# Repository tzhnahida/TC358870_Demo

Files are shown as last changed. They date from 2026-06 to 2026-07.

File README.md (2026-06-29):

# TC358870XBG HDMI-to-MIPI DSI Bridge — Evaluation Board

> **PCB Rev 1.0 is deprecated.** Do not fabricate. MIPI DSI lane swap errata + HPD wiring errors.
> **Rev 2.0:** Layout complete. HDMI SI/PI simulation passed. Gerber released — ready for fabrication.

A 4-layer PCB for the Toshiba TC358870XBG, converting HDMI 1.4b (up to 297 MHz TMDS) to dual 4-lane MIPI DSI (up to 1 Gbps/lane). Designed to drive a Sharp LS029B3SX01 1440×1440@90Hz LCD panel.

---

## Hardware

### Key Components

| Designator | Part | Function |
|---|---|---|
| U1 | TYPE-C 16-pin | 5V power input (USB-C) |
| U2 | TLV62569DBV | 5V→3.3V DCDC buck (VCC_3V3) |
| U3 | LP5907MFX | 3.3V→1.2V LDO (VCC_1V2) |
| U4 | TLV62569DBV | 5V→1.1V DCDC buck (VCC_1V1) |
| U5 | LP5907MFX | 3.3V→1.8V LDO (VCC_1V8) |
| U6 | TPS65131RGER | 5V→±5.5V charge pump (panel AVDD/AVEE) |
| U7 | SGM3752YTN6G | 3.3V→LED backlight boost (22mA max) |
| U8 | AT24C02 (SOP-8) | DDC EEPROM, EDID storage |
| U9A/B/C/D | TC358870XBG (BGA80) | HDMI Rx → dual MIPI DSI Tx (4-page schematic) |
| ESD1/2/3 | IP4292CZ10 | HDMI ESD protection |
| Q1 | PMOS | Power switch |
| OSC1 | 40 MHz | REFCLK for TC358870 |
| J1 | HDMI-A | HDMI input connector |
| J2 | WP7 (JAE 40-pin) | Panel FPC, mates with LS029B3SX01 |

### Power Rails

| Rail | Voltage | Source | Load |
|---|---|---|---|
| VCC_5V | 5.0V | USB-C | Input bus |
| VCC_3V3 | 3.3V | 5V→3.3V DCDC buck (TLV62569) | TC358870 VDDIO33, VDD33_HDMI; feeds LDOs + LED |
| VCC_1V8 | 1.8V | 3.3V→1.8V LDO (LP5907) | TC358870 VDDIO18 |
| VCC_1V2 | 1.2V | 3.3V→1.2V LDO (LP5907) | TC358870 VDD12_MIPI0/1 |
| VCC_1V1 | 1.1V | 5V→1.1V DCDC buck (TLV62569) | TC358870 VDDC11, VDD11_HDMI |
| VCC_5V5 | +5.5V | 5V charge pump (TPS65131) | LS029 AVDD+ |
| VEE_5V5 | -5.5V | 5V charge pump (TPS65131) | LS029 AVEE- |
| VCC_HDMIRX_IN | +5V (from HDMI source) | HDMI pin 18 | DDC pull-up |

### PCB Stack-Up (4-layer)

| Layer | Type |
|---|---|
| TOP | Signal (HDMI, MIPI, I2C, REFCLK) |
| L2 | Solid GND plane |
| L3 | Split POWER plane |
| BOTTOM | Signal, decoupling, test points |

---

## Known Issues

### AT24C256 → AT24C02 ✅ Resolved in Schematic

Schematic symbol value updated to AT24C02 (2026-06-29). Original AT24C256 uses **2-byte I2C addressing** — incompatible with HDMI DDC which only sends 1 address byte for EDID reads. AT24C02 uses same SOP-8 footprint and 1-byte addressing (¥0.5). PCB footprint unchanged. Library symbol name still shows "AT24C256" but BOM and silk-screen will read AT24C02.

### EDID: External EEPROM Only

TC358870 contains 1 KB internal EDID SRAM, but **its I2C sub-address is not documented in the public datasheet** (`TC358870XBG_rev1.3.pdf`). Use external AT24C02 on the DDC bus with `EDID_MODE = 0x00` (DDC passthrough to EEPROM).

### Rev 1.0 Errata

| Signal | Issue | Fix |
|---|---|-----|
| MIPI DSI lanes | Lane/clock pair order swapped per datasheet | Re-route per pin mapping |
| HPDO (B4) | Shorted to +5V | Cut trace, add 1kΩ to HDMI pin 19 |
| HPDI (A4) | Connected to HPD pin | Move to HDMI pin 18 (+5V) via 100kΩ |

---

## EDID

The board ships with a 256-byte EDID for LS029B3SX01 (1440×1440@90.2Hz). Flash this to the AT24C02 via the DDC bus (STM32 can take control while TC358870 is held in reset):

```c
const uint8_t edid_ls029b3sx01[256] = {
    0x00,0xFF,0xFF,0xFF,0xFF,0xFF,0xFF,0x00,
    0x4D,0x10,0x02,0x29,0x01,0x00,0x00,0x00,
    0x1A,0x24,0x01,0x03,0x80,0x34,0x34,0x78,
    0xEE,0x91,0x50,0x54,0x9C,0x27,0x0E,0x50,
    0x54,0xBF,0xEF,0x00,0x00,0x00,0x01,0x01,
    0x01,0x01,0x01,0x01,0x01,0x01,0x01,0x01,
    0x01,0x01,0x01,0x01,0x01,0x01,0x2F,0x66,
    0xA0,0xFE,0x50,0xA0,0x10,0x51,0x9A,0x04,
    0xF1,0xC0,0x34,0x34,0x10,0x00,0x00,0x00,
    0x00,0x00,0x00,0x00,0x00,0x00,0x00,0x00,
    0x00,0x00,0x00,0x00,0x00,0x00,0x00,0x00,
    0x00,0x00,0x00,0x00,0x00,0xFD,0x00,0x32,
    0x5E,0x14,0xA0,0x1E,0x00,0x00,0x00,0x00,
    0x00,0x0A,0x00,0x00,0x00,0x00,0x00,0xFC,
    0x00,0x4C,0x53,0x30,0x32,0x39,0x42,0x33,
    0x53,0x58,0x30,0x31,0x00,0x00,0x01,0x19,
    0x02,0x03,0x0E,0x00,0x21,0x01,0x67,0x00,
    0x0C,0x03,0x01,0x00,0x00,0x00,0x00,0x00,
    // ... (see wiki LS029B3SX01.md for full verified array)
};
// Checksums: Block0=0x19, Block1=0x54
// 1440×1440, 261.6 MHz pixel clock, 90.2 Hz
```

---

## Firmware

### Register Initialization Sequence

The STM32 (or any I2C master at 0x0F/0x1F) must write this sequence at power-up:

```
 1. SYSCTL     (0x0002) = 0x3F01   // full reset + SLEEP, delay 1ms
 2. SYSCTL     (0x0002) = 0x0000   // release
 3. ConfCtl0   (0x0004) = 0x0004   // AutoIndex=1
 4. ConfCtl1   (0x0006) = 0x0008   // dcs_clks=1
 5. SYS_FREQ0  (0x8540) = ...      // REFCLK_Hz / 10000  LSB
 6. SYS_FREQ1  (0x8541) = ...      // REFCLK_Hz / 10000  MSB
 7. EDID_MODE  (0x85E0) = 0x00     // DDC passthrough to external EEPROM
 8. DDCIO_CTL  (0x84F4): 0→1      // DDC I/O power-up edge
 9. DDC_CTL    (0x8543) = 0x04     // DDC_ACTION=1
10. PHY_ENB    (0x8413) |= 0x01    // exit Suspend
11. PHY_RSTX   (0x8414) |= 0x01    // release PHY reset
12. VOUT_FMT   (0x8A00) = 0x00     // RGB output
13. VOUT_CSC   (0x8A08) = 0x00     // no CSC
14. ConfCtl0   (0x0004) = 0x0007   // Vtx0_en + Vtx1_en + AutoIndex
15. INIT_END   (0x854A) = 0x01     // init complete
16. HPD_CTL    (0x8544) = 0x01     // assert HPD
```

### DSI Configuration (40 MHz REFCLK, 800 Mbps/lane target)

```
MIPI_PLL_CONF (0x02AC) = 0x0003793F  // {0x3F,0x79,0x03,0x00}
//   FBD=319, PRD=7, FRS=2, LBW=max
//   pll_clk = 40MHz × 320/8 / 4 = 400 MHz → 800 Mbps/lane

MIPI_PLL_CTRL (0x02A0) = 0x03        // MP_ENABLE + MP_CKEN
while (!(read(0x02A8) & 0x01));       // wait for PLL lock

PPI_DPHY_POWERCNTRL (0x0284) = 0x1F
DSITX_CLKEN   (0x0108)  = 0x01
MODE_CONFIG   (0x0110)  = 0x16    // IndMode=1, HSYNC/VSYNC active-low
FUNC_MODE     (0x0150)  = 0x00    // discontinuous clock, no EoT
DSITX_MODE    (0x017C)  = 0x00    // LP blanking, pulse mode
LANE_ENABLE   (0x0118)  = 0x1F    // CK + D0-D3 all lanes
DSI_HSYNC_WIDTH (0x018C) = 0x0004
DSI_HBPR      (0x0190) = 0x0092
```

### Panel DCS Initialization

LS029B3SX01 uses an NT35597 driver IC with NVM pre-programmed by Sharp. Only 5 DCS commands needed (sent via TC358870 LPTX registers in LP mode, before video starts):

| Step | Command | Data Type | Wait |
|---|---|---|---|
| 1 | `0xFF 0x10` | DCS Short Write 1p (0x15) | — |
| 2 | `0x11` (Sleep Out) | DCS Short Write 0p (0x05) | ≥100ms |
| 3 | `0xFF 0x10` | DCS Short Write 1p (0x15) | — |
| 4 | `0x29` (Display On) | DCS Short Write 0p (0x05) | ≥40ms |

LPTX register sequence per command:
```c
LPTX_TYPE        (0x022C) = 0x00000384;   // Trigger0, LPDT=1, ALL lanes
DSI_LPTX_PKT_HDR (0x0230) = <packed DT+WC>; // e.g. 0x10FF0015 for DT=0x15, cmd=0xFF
DSI_LPTX_REQ     (0x0228) = 0x01;
while (!(read(0x0220) & 0x01));            // wait LpTxDone
write(0x0220) = 0x01;                      // clear
```

After DCS commands complete, start HS video:
```c
DSITX_START (0x011C) = 0x01;
```

### Panel Hardware Power-Up (MCU GPIO control, before DCS)

```
1. XRES = L (assert reset)
2. IOVDD 1.8V ON → wait stable
3. AVDD+ 5.5V ON → wait >1ms
4. AVDD- -5.5V ON → wait >10ms
5. XRES = H → ≥20µs → L → ≥20µs → H
6. Wait ≥10ms (NVM auto-load)
```

---

## Key Registers Reference

Full register documentation is in `TC358870XBG_rev1.3.pdf` (311 pages). See wiki `TC358870.md` for the complete register map with bit-level definitions.

| Address | Register | Summary |
|---|---|---|
| `0x0000` | ChipID | RO, `0x0047` |
| `0x0002` | SysCtl | Reset bits [13:6], SLEEP [0] |
| `0x0004` | ConfCtl0 | Vtx0_en [0], Vtx1_en [1], AutoIndex [2] |
| `0x0006` | ConfCtl1 | dcs_clks [3] |
| `0x0108` | DSITX_CLKEN | DSI0 clock enable |
| `0x0110` | MODE_CONFIG | IndMode [4], HSYNC_POL [2], VSYNC_POL [1] |
| `0x0118` | LANE_ENABLE | Lane enable [4:0] = CK/D0/D1/D2/D3 |
| `0x011C` | DSITX_START | Write 1 to start video |
| `0x0150` | FUNC_MODE | HsCkMd [5], EoTpEn [0] |
| `0x017C` | DSITX_MODE | BlankPkt_En [7], DSITXMd [0] |
| `0x018C` | DSI_HSYNC_WIDTH | HSA in bytes |
| `0x0190` | DSI_HBPR | HBP in bytes |
| `0x0220-0x0238` | LPTX regs | LP-mode DCS command transmission |
| `0x0284` | PPI_DPHY_POWERCNTRL | D-PHY lane power |
| `0x02A0` | MIPI_PLL_CTRL | MP_ENABLE, MP_CKEN |
| `0x02A8` | MIPI_PLL_LOCK | RO, bit[0]=1 when locked |
| `0x02AC` | MIPI_PLL_CONF | FBD[8:0], PRD[3:0], FRS[1:0], LBW[1:0] |
| `0x5000` | STX0_CTRL | Splitter control (manual/auto) |
| `0x500C` | STX0_FPX | STX0 first pixel (0-4095) |
| `0x500E` | STX0_LPX | STX0 last pixel |
| `0x508C` | STX1_FPX | STX1 first pixel |
| `0x508E` | STX1_LPX | STX1 last pixel |
| `0x8410` | PHY_CTL | PHYCtl [0]: 0=manual, 1=auto |
| `0x8413` | PHY_ENB | PHYEnb [0] |
| `0x8414` | PHY_RSTX | PHY reset [0] |
| `0x84F4` | DDCIO_CTL | DDCPWR [0]: 0→1 edge required |
| `0x8520` | SYS_STATUS | S_DDC5V [0], S_TMDS [1], S_PHY_SCDT [3] |
| `0x8540-0x8541` | SYS_FREQ | REFCLK_Hz / 10000 |
| `0x8543` | DDC_CTL | DDC_ACTION [2], DDC5V_MODE [1:0] |
| `0x8544` | HPD_CTL | HPD_CTL0 [1], HPD_OUT0 [0] |
| `0x854A` | INIT_END | Write 0x01 to complete init |
| `0x85E0` | EDID_MODE | 00=external EEPROM, 01=internal+DDC2B, 1x=internal+E-DDC |
| `0x85E3` | EDID_LEN1 | EDID length [7:0] |
| `0x85E4` | EDID_LEN2 | EDID length [10:8] |
| `0x8A00` | VOUT_FMT | VOUT_SEL [1:0] |
| `0x8A08` | VOUT_CSC | VOUT_COLOR_SEL [6:4], CSC_Mode [1:0] |

---

## Files

| File | Description |
|---|---|
| `TC358870_DEMO.DSN` | OrCAD Capture schematic |
| `TC358870_Demo.opj` | OrCAD project |
| `TC358870_DEMO.pdf` | Schematic PDF |
| `allegro/tc358870_demo.brd` | Allegro PCB layout (Rev 2.0) |
| `allegro/gerber.zip` | Gerber fabrication files (Rev 2.0) |
| `allegro/tc358870_demo.ipc` | IPC-D-356A netlist for bare-board testing |
| `allegro/signoise.run/` | Cadence SigNoise SI/PI simulation config & data |
| `Test_code/` | STM32F103 firmware (Keil MDK-ARM) |

---

## Panel

| Parameter | Value |
|---|---|
| Model | Sharp LS029B3SX01 |
| Resolution | 1440×1440 |
| Refresh | 90.2 Hz |
| Interface | MIPI DSI dual 4-lane |
| DSI rate | 784.8 Mbps/lane |
| Driver IC | NT35597 (NVM pre-configured) |
| Connector | JAE WP7B-P040VA1 (40-pin B2B) |

See wiki `LS029B3SX01.md` for full datasheet parameters, DCS init sequence, DSI timing, and EDID binary.

---

## License

Apache 2.0. See [LICENSE](LICENSE).

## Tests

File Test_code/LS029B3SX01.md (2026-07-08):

---
type: entity
tags: [electronics, display, microdisplay, lcd, cgs, sharp, mipi]
created: 2026-06-18
updated: 2026-06-25
sources: ["[[2026-06-18 - LS029B3SX01 数据手册]]"]
---

# LS029B3SX01

> Sharp 2.89 寸 CG-Silicon TFT LCD 微显示模组。1440×1440, MIPI DSI 双端口, 90Hz。SPEC LCY-1315802C Rev.C, 38 pages.

## 1. 身份与选型

- **型号**: LS029B3SX01
- **类型**: CG-Silicon (Continuous Grain Silicon) TFT LCD
- **分辨率**: 1440 × 1440 (1:1 方形)
- **尺寸**: 2.89 寸对角线 (73.4mm)
- **有效区域**: 51.84 × 51.84mm
- **色彩**: 16,777,216 色 (24-bit RGB)
- **接口**: MIPI DSI (双端口, 8 lane 无压缩 / 4 lane 压缩)
- **驱动 IC**: NT35597 (内置 1/3 RAM + NVM)
- **连接器**: JAE WP7B-P040VA1 (40-pin Board-to-Board)
- **厂商**: Sharp Corporation

> [!warning] 注意
> 项目页中曾标注为 "0.29 寸 Micro OLED, 1280×720"——实际为 **2.89 寸 CGS LCD, 1440×1440**。
> 0.29 寸是 2.89 寸小数点错位；LS029B3SX 系列没有 1280×720 分辨率，全部为方形。

## 2. 极限工况

| 参数 | 值 | 备注 |
|---|-----|---|
| AVDD (正模拟) | -0.3 – +6.5V | GND=0V, Ta=25°C |
| AVEE (负模拟) | +0.3 – -6.5V | GND=0V |
| VDDI (数字) | -0.3 – +5.5V | GND=0V |
| 工作温度 | -20 – +60°C | |
| 存储温度 | -30 – +70°C | 湿度 95%RH Max (@40°C) |
| LED 电流 | 25mA Max | 每颗 |

## 3. 推荐工作条件

| 参数 | 符号 | 典型值 | 范围 | 备注 |
|---|---|---|---|---|
| 数字供电 | VDDI | 1.80V | 1.70–1.90V | |
| 正模拟供电 | AVDD | 5.5V | 5.3–5.7V | |
| 负模拟供电 | AVEE | -5.5V | -5.7 – -5.3V | |
| LED 电压 | VLED | 2.9V | — | 每颗 |
| LED 电流 | ILED | 11mA | — | 每颗，共 8 颗 |
| 工作温度 | Topr | — | -20 – +60°C | |

## 4. 功耗与热特性

| 参数 | 值 | 备注 |
|---|-----|---|
| LED 背光功耗 | 255.2mW | 8 颗 LED × 2.9V × 11mA |
| LED 拓扑 | **2P4S** | 2 路并联 × 4 颗串联 |
| LED 总电流 | 22mA | 2 路 × 11mA，经 RSET 采样 |
| AVDD 电流 (视频模式) | TBD | 数据手册未给出 |
| AVEE 电流 (视频模式) | TBD | 数据手册未给出 |
| 面板透射式 | — | 需要背光正常工作 |

## 5. 光学特性

| 参数 | 典型值 | 范围 | 备注 |
|---|---|---|---|
| 对比度 | **1100:1** | ≥770 | @θ=φ=0° |
| 响应时间 | **10ms** | — | Tr+Td, Black↔White |
| 亮度 | 300 cd/m² | ≥210 | ILED=11mA/pcs |
| 均匀度 | — | ≥70% | 9 点法 |
| NTSC 色域 | **75%** | — | |
| Gamma | 2.2 | 1.8–2.6 | |
| 视角 (CR>10) | 80° 全向 | — | IPS 级 |
| 白点色度 x | 0.290 | 0.240–0.340 | 接近 D65 |
| 白点色度 y | 0.315 | 0.265–0.365 | |
| Flicker | — | ≤30% | |
| Crosstalk | — | ≤5% | |

> VDDI=1.8V, AVDD=5.5V, AVEE=-5.5V, ILED=11mA/pcs, Ta=25°C, 60Hz 帧频

## 6. I/O 接口特性

### 电气特性

| 参数 | 符号 | 值 | 备注 |
|---|---|-----|---|
| 输入低电平 | VIL | 0 – 0.3×VDDI | |
| 输入高电平 | VIH | 0.7×VDDI – VDDI | |
| 输入漏电流 | IIL/IIH | ±10µA | |
| 输出低电平 | VOL | 0 – 0.2×VDDI | IOL=+0.1mA |
| 输出高电平 | VOH | 0.8×VDDI – VDDI | IOH=-0.1mA |

### SDC 显示时序 (8-lane 无压缩, Table 14)

| 参数 | 典型值 | 单位 |
|---|---|---|
| 水平有效 (H Active) | 1440 | px |
| 水平同步+后廊 (HS+HBP) | 100 | px |
| 水平前廊 (HFP) | 154 | px |
| **水平总量** | **1694** | px |
| 垂直有效 (V Active) | 1440 | H |
| 垂直同步脉冲 (VS) | 1 | H |
| 垂直后廊 (VBP) | 7 | H |
| 垂直前廊 (VFP) | 264 | H |
| **垂直总量** | **1712** | H |
| 帧频 | 90.2 (87.3–92.7) | Hz |
| 行时间 (1H) | 6.476 | µs |
| DSI 数据率 | 784.8 (Max 808.3) | Mbps/Lane |
| 像素时钟 | **261.6** | MHz |

> 像素时钟 = 1694 × 1712 × 90.2 ≈ 261.6 MHz

### 4-lane 压缩模式 (VESA DSC)

| 参数 | 典型值 | 单位 |
|---|---|---|
| 水平有效 (压缩后) | 480 | px |
| 水平同步+后廊 | 46 | px |
| 水平前廊 | 100 | px |
| 水平总量 | 626 | px |
| DSI 数据率 | ~580 | Mbps/Lane |

## 7. 驱动初始化

### 驱动 IC

NT35597，内置 1/3 RAM 和 NVM（非易失存储器）。Sharp 出厂时已将大部分寄存器配置烧录进 NVM，因此初始化只需 5 条 DCS 命令。

> 对比：纯 NT35597 面板（如 Linux 内核 `panel-truly-nt35597.c`）需要 200+ 条命令；LS029B3SX01 的 NVM 自动加载省掉了这些。

### 硬件上电序列 (Table 17)

```
1. XRES = L
2. IOVDD 1.8V 上电 → 等稳定 (>0ms)
3. AVDD+ 5.5V 上电 → 等 >1ms (上升斜率 >0.2ms)
4. AVDD- -5.5V 上电 → 等 >10ms
5. XRES = H → ≥20µs → XRES = L → ≥20µs → XRES = H
6. 等 ≥10ms [NVM 自动加载完成, 面板进入 Sleep Mode]
```

### DCS 初始化命令 (LP 模式)

| 序号 | 命令 | Data Type | 说明 |
|---|---|---|---|
| 1 | `0xFF 0x10` | `0x15` (DCS Short Write 1p) | Page Select → CMD1 |
| 2 | `0x11` | `0x05` (DCS Short Write 0p) | Sleep Out |
| | | | **等 ≥100ms** |
| 3 | `0xFF 0x10` | `0x15` | Page Select → CMD1 |
| 4 | `0x29` | `0x05` | Display On |
| | | | **等 ≥40ms** |

> [!warning] 必须在 CMD1 页面（`0xFF 0x10`）下发送 Sleep Out 和 Display On。XRES 复位后默认进入 CMD1 页面，但 Sleep Out 后会自动退出；Display On 前必须再次切回 CMD1。

### TC358870 驱动配置

#### DCS 命令通过 LPTX 寄存器发送 (LP 模式, 视频启动前)

```c
// 每一条 DCS Short Write (1 param, DT=0x15):
LPTX_TYPE        (0x022C) = 0x00000384   // Trigger0 + LPDT=1 + ALL lanes
DSI_LPTX_PKT_HDR (0x0230) = 0x10FF0005   // DT=0x15, WC0=0xFF, WC1=0x10
DSI_LPTX_REQ     (0x0228) = 0x01         // 触发
while(!(read(0x0220) & 0x01));           // 等 LpTxDone
write(0x0220) = 0x01;                    // 清中断

// 每一条 DCS Short Write (no param, DT=0x05):
DSI_LPTX_PKT_HDR (0x0230) = 0x00110005   // DT=0x05, WC0=0x11 (Sleep Out)
// 或
DSI_LPTX_PKT_HDR (0x0230) = 0x00290005   // DT=0x05, WC0=0x29 (Display On)
```

#### DSI PLL (40MHz REFCLK, 目标 400MHz, 800Mbps/lane)

```
MIPI_PLL_CONF (0x02AC) = 0x0003793F   // 4字节: {0x3F,0x79,0x03,0x00}
//   bit[17:16] LBW = 11 (max bandwidth)
//   bit[15:12] PRD = 7 → ÷8
//   bit[11:10] FRS = 2 → ÷4
//   bit[8:0]   FBD = 319 → ×320
//   pll_clk = 40MHz × 320/8 / 4 = 400MHz → 800Mbps/lane
MIPI_PLL_CTRL (0x02A0) = 0x03          // MP_ENABLE + MP_CKEN
while(!(read(0x02A8) & 0x01));          // 等 PLL lock

PPI_DPHY_POWERCNTRL (0x0284) = 0x1F     // 全部 Lane 上电
DSITX_CLKEN   (0x0108) = 0x01
```

#### DSI 模式配置

```
MODE_CONFIG (0x0110) = 0x16    // IndMode=1(LP命令), HSYNC/VSYNC=ActiveLow(DSI要求)
FUNC_MODE   (0x0150) = 0x00    // HsCkMd=0(非连续时钟), EoTpEn=0
DSITX_MODE  (0x017C) = 0x00    // BlankPkt_En=0(LP消隐), Pulse Mode
LANE_ENABLE (0x0118) = 0x1F    // CK + D0-D3 全部使能
```

#### DSI 视频时序 (对应 1694×1712 总量, DSI0 半幅)

```
DSI_HSYNC_WIDTH (0x018C) = 0x0004   // HSA ≈ 4 bytes
DSI_HBPR       (0x0190) = 0x0092   // HBP ≈ 146 bytes (150-4)
// TC358870 自动从 HDMI 输入时序继承, 消隐编码由 DSITX_MODE 控制
```

### MIPI 双端口模式

- **Port A** (DSIA): 4 data lanes + 1 clock lane → 接 TC358870 DSI0
- **Port B** (DSIB): 4 data lanes + 1 clock lane → 接 TC358870 DSI1
- **EN1PORT** 引脚 = L (双端口使能)
- 单端口模式下仅 DSIA 工作，DSIB 可悬空

### EDID (256 字节, 校验通过)

```c
const uint8_t edid_ls029b3sx01[256] = {
    0x00,0xFF,0xFF,0xFF,0xFF,0xFF,0xFF,0x00,
    0x4D,0x10,0x02,0x29,0x01,0x00,0x00,0x00,
    0x1A,0x24,0x01,0x03,0x80,0x34,0x34,0x78,
    0xEE,0x91,0x50,0x54,0x9C,0x27,0x0E,0x50,
    0x54,0xBF,0xEF,0x00,0x00,0x00,0x01,0x01,
    0x01,0x01,0x01,0x01,0x01,0x01,0x01,0x01,
    0x01,0x01,0x01,0x01,0x01,0x01,0x2F,0x66,
    0xA0,0xFE,0x50,0xA0,0x10,0x51,0x9A,0x04,
    0xF1,0xC0,0x34,0x34,0x10,0x00,0x00,0x00,
    0x00,0x00,0x00,0x00,0x00,0x00,0x00,0x00,
    0x00,0x00,0x00,0x00,0x00,0x00,0x00,0x00,
    0x00,0x00,0x00,0x00,0x00,0xFD,0x00,0x32,
    0x5E,0x14,0xA0,0x1E,0x00,0x00,0x00,0x00,
    0x00,0x0A,0x00,0x00,0x00,0x00,0x00,0xFC,
    0x00,0x4C,0x53,0x30,0x32,0x39,0x42,0x33,
    0x53,0x58,0x30,0x31,0x00,0x00,0x01,0x19,
    0x02,0x03,0x0E,0x00,0x21,0x01,0x67,0x00,
    0x0C,0x03,0x01,0x00,0x00,0x00,0x00,0x00,
    0x00,0x00,0x00,0x00,0x00,0x00,0x00,0x00,
    0x00,0x00,0x00,0x00,0x00,0x00,0x00,0x00,
    0x00,0x00,0x00,0x00,0x00,0x00,0x00,0x00,
    0x00,0x00,0x00,0x00,0x00,0x00,0x00,0x00,
    0x00,0x00,0x00,0x00,0x00,0x00,0x00,0x00,
    0x00,0x00,0x00,0x00,0x00,0x00,0x00,0x00,
    0x00,0x00,0x00,0x00,0x00,0x00,0x00,0x00,
    0x00,0x00,0x00,0x00,0x00,0x00,0x00,0x00,
    0x00,0x00,0x00,0x00,0x00,0x00,0x00,0x00,
    0x00,0x00,0x00,0x00,0x00,0x00,0x00,0x00,
    0x00,0x00,0x00,0x00,0x00,0x00,0x00,0x00,
    0x00,0x00,0x00,0x00,0x00,0x00,0x00,0x00,
    0x00,0x00,0x00,0x00,0x00,0x00,0x00,0x00,
    0x00,0x00,0x00,0x00,0x00,0x00,0x00,0x54,
};
```

> SHP (Sharp) · 1440×1440 · 261.6MHz · 90.2Hz · Block0 CS=0x19 · Block1 CS=0x54
> VFP 从 264 压缩到 63（EDID 1.3 6-bit 限制），VBP 从 7 扩到 208 补偿，总量 1712 不变。

### CG-Silicon 特点

- 相比 a-Si TFT，电子迁移率更高 → 驱动 IC 可部分集成到玻璃上
- 支持 DC Driving / 1H Z-Inversion，降低闪烁
- Normally Black 模式，黑色更纯净

## 8. 封装

- **外形尺寸**: 54.24 × 59.02 × 1.365mm (不含 FPC 突出部)
- **重量**: 7g
- **连接方式**: 40-pin Board-to-Board Plug (JAE WP7B-P040VA1)
- **FPC**: 含 LED 背光供电、MIPI 信号、控制信号
- **面板结构**: LCD 面板 + COG 驱动 + FPC + LED + 棱镜片 + 扩散片 + 导光板 + 反射片 + 塑料框架

## 参见

- [[TC358870]] — HDMI→MIPI DSI 桥接芯片（含完整寄存器表、EDID 方案、LPTX DCS 发包）
- [[SGM3752]] — 背光 LED 驱动（2P4S, RSET=9.1Ω, 22mA）
- [[全身动捕与头显系统]] — 应用项目
- [[2026-06-18 - LS029B3SX01 数据手册]] — 来源摘要
- `LS029B3SX01.pdf` — 38 页完整数据手册 (LCY-1315802C Rev.C)
- `panel-truly-nt35597.c` — Linux 内核 NT35597 驱动 (参考, 1440×2560 variant)

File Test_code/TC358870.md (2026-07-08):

---
type: entity
tags: [electronics, video-interface, bridge, toshiba, mobile]
created: 2026-06-07
updated: 2026-06-25
---

# TC358870
> 东芝 (Toshiba) HDMI 1.4b → 双 MIPI DSI 视频桥接芯片。4K×2K@30fps。VFBGA80。

## 1. 身份与选型

| 项目 | 内容 |
|---|---|
| 型号 | TC358870XBG |
| 核心功能 | HDMI 1.4b → 双 MIPI DSI 显示桥接 |
| 关键卖点 | 4K@30 输入、双路 DSI 输出、低功耗 |
| 竞品对比 | 功能相近 [[LT7911D]] / [[TC358860]] / [[TC358870XL]] |

## 2. 极限工况

> ⚠️ 超过即永久损坏

| 参数 | 最小 | 最大 | 单位 |
|---|---|---|---|
| VDD33, VDD18 | -0.3 | 4.0 | V |
| VDD12 | -0.3 | 1.5 | V |
| HDMI 引脚 | -0.3 | 3.6 | V |
| 存储温度 | -55 | 150 | °C |
| 结温 TJ | -40 | 125 | °C |
| ESD (HBM) | — | ±2000 | V |

## 3. 推荐工作条件

| 参数 | 最小 | 典型 | 最大 | 单位 |
|---|---|---|---|---|
| VDD33 | 3.0 | 3.3 | 3.6 | V |
| VDD18 | 1.7 | 1.8 | 1.9 | V |
| VDD12 | 1.1 | 1.2 | 1.3 | V |
| HDMI TMDS 速率 | — | — | 297 | MHz |
| HDMI 带宽 | — | — | 7.2 | Gbps |
| MIPI DSI 速率 | — | — | 1.0 | Gbps/ch |
| I2C 频率 | — | — | 2.0 | MHz |
| TA | -20 | — | 70 | °C |

## 4. 功耗与供电特性

| 参数 | 条件 | 典型 | 单位 |
|---|---|---|---|
| 总功耗 | 1080p@60fps | 420 | mW |
| 总功耗 | 4K×2K@30fps | 520 | mW |
| VDD33 电流 | 4K | — | mA |
| VDD18 电流 | 4K | — | mA |
| VDD12 电流 | 4K | — | mA |
| 待机功耗 | — | — | mW |

## 5. 通信/接口特性

| 参数 | 条件 | 值 |
|---|---|-----|
| 输入协议 | HDMI | 1.4b |
| TMDS 时钟 | — | 最高 297 MHz |
| 输入带宽 | — | 7.2 Gbps |
| 最大分辨率 | — | 4K×2K (3840×2160) @30fps |
| 色彩深度 | — | 24/30/36 bit RGB/YCbCr |
| 输出协议 | — | 双 MIPI DSI |
| 输出通道 | 每 MIPI | 4 lane (最高 1Gbps/lane) |
| 输出带宽 | 双 × 4ch × 1Gbps | 8 Gbps |
| HDMI CEC | — | 支持 |
| HDCP | — | 1.4 |
| I2C 接口 | 控制/配置 | 100kHz / 400kHz / 2MHz |
| 音频接口 | I2S | 4 线，5.1/7.1ch，192kHz |
| 红外接收 | NEC 协议 | 输入 |

## 6. 核心功能

- **HDMI → MIPI 桥接**：将 HDMI 1.4b 视频流转换为双 MIPI DSI（支持双端口模式扩展带宽）→ 视频显示/MIPI DSI
- **4K 支持**：输入 4K×2K@30fps，通过双路 DSI 输出保证 8Gbps 带宽足够传输
- **音频提取**：从 HDMI 流中提取音频，通过 I2S 接口输出 5.1/7.1ch 环绕声 → 数字音频接口 I2S
- **HDCP 1.4 解密**：支持内容保护解密，用于合法播放受保护内容
- **EDID 管理**：片上 EDID ROM，可通过 I2C 在线更新
- **缩放与颜色空间转换**：输入到输出 RGB/YCbCr 格式转换
- **CEC 遥控**：HDMI CEC 总线控制，支持 NEC 红外远程输入

## 7. 引脚定义

### 7.1 HDMI / DDC 引脚

| Ball | 引脚名 | I/O | 类型 | 功能 | 电源域 |
|---|---|-----|---|---|---|
| A3 | **DDC_SCL** | IO | Schmitt / 5V / OD | DDC I2C Slave 时钟，5V 容忍 | VDDIO33 |
| B3 | **DDC_SDA** | IO | Schmitt / 5V / OD | DDC I2C Slave 数据，5V 容忍 | VDDIO33 |
| A4 | **HPDI** | I | 5V | HDMI +5V 电源检测 | VDDIO33 |
| B4 | **HPDO** | O | N-ch Open Drain | Hot Plug Detect 输出 | VDDIO33 |
| A2 | **CEC** | IO | Schmitt / OD | HDMI CEC 控制 | VDDIO33 |
| A1 | **REXT** | I | HDMI-PHY | 外接 **2kΩ±1%** 到 VDD33_HDMI | VDD33_HDMI |

### 7.2 TMDS 差分对

| Ball | 引脚名 | 功能 |
|---|---|---|
| C1/C2 | HDMICP/N | TMDS 时钟 |
| D1/D2 | HDMID0P/N | TMDS 数据 0 |
| E1/E2 | HDMID1P/N | TMDS 数据 1 |
| F1/F2 | HDMID2P/N | TMDS 数据 2 |

### 7.3 其余引脚分组

| 组 | 引脚 | 说明 |
|----|---|---|
| MIPI 输出 | DSI0 D0–3± CLK±, DSI1 D0–3± CLK± | 双路 4-lane MIPI DSI |
| 音频 I2S | A_SCK (K7), A_WFS (K5), A_SD[3:0] (J5–J9) | 4 线 I2S / TDM |
| 控制 I2C | I2C_SCL, I2C_SDA | Host MCU 配置接口, 地址 0x0F 或 0x1F |
| 系统 | RESETN (K8), INT (J3), REFCLK (K9), TEST (G5) | 复位/中断/参考时钟 40–50MHz |

## 8. EDID 方案：外挂 24C02 EEPROM

> [!warning] 公开手册未写明内部 EDID_SRAM 的 I2C 子地址。
> 因此最稳妥的方案是外挂一颗标准 I2C EEPROM (AT24C02)。

### EDID_MODE 寄存器 (0x85E0)

| bit[1:0] | 模式 | 行为 |
|---|---|---|
| `00` | **DDC 直通外部 EEPROM** | 芯片完全不响应 DDC 读取，DDC_SCL/DDC_SDA 直通外部总线 |
| `01` | 内部 EDID-RAM + DDC2B | 芯片响应 DDC 读取（内部 RAM） |
| `1x` | 内部 EDID-RAM + E-DDC | 芯片响应 DDC 读取，支持 E-DDC segment pointer |

**模式 `00` = 外挂 EEPROM**。DDC 总线上的 EDID 读请求 (I2C 地址 0xA0) 由外部 EEPROM 应答。

### 电路连接

```
HDMI +5V ──┬──────────────────── HPDI (A4)
           ├── 47kΩ ──────────── DDC_SCL (A3) ─── AT24C02 SCL
           ├── 47kΩ ──────────── DDC_SDA (B3) ─── AT24C02 SDA
           │                                       AT24C02 VCC ← +5V
           │                                       AT24C02 WP → GND
 HPD ──────┤
           ├── 100kΩ ─────────── GND
           └── 1kΩ ──────────── HPDO (B4)

 REXT (A1) ─── 2kΩ±1% ──────── VDD33_HDMI
 INT (J3) ─── 10kΩ → VDDIO18 或 GND  (上拉=0x1F, 下拉=0x0F)
```

### AT24C02 和调试注意事项

- SOP-8 封装，与 24C256/512 脚位兼容
- I2C 地址固定 0x50（A0/A1/A2 全接地）
- 供电用 HDMI +5V（不用系统电源）→ 电平匹配 DDC 5V 总线
- FT（5V 容忍）MCU（STM32F103/G431）可直接挂 DDC 总线调试写 EDID
- I2C 开漏：MCU 只拉低不推高，高电平由外部 47kΩ 上拉提供

## 9. 寄存器总表

> I2C 控制接口：0x0F 或 0x1F（INT 引脚选择）。HDMI 寄存器 8-bit，DSI/CEC 寄存器 32-bit。

### 9.1 地址映射概览

| 段地址 | 模块 |
|---|---|
| `0x0000-0x0013` | Global Control (ChipID, SYSCTL, ConfCtl) |
| `0x0014-0x001F` | Interrupt |
| `0x0028-0x00DF` | IR Control (NEC 红外) |
| `0x0080-0x008F` | IO Control |
| `0x0100-0x02FF` | DSI0-TX (~70 个寄存器) |
| `0x0300-0x04FF` | DSI1-TX (DSI0 镜像, +0x0200) |
| `0x0500-0x05FF` | DSI Wrapper (命令队列 DCSCMD_Q) |
| `0x0600-0x06FF` | CEC |
| `0x5000-0x5FFF` | Splitter (STX0/STX1) |
| `0x7000-0x709F` | Color Bar |
| `0x8000-0x9FFF` | **HDMIRX** (含 EDID_SRAM 1KB 缓冲区) |
| `0x8410-0x84F4` | HDMI PHY/DDCIO/APLL |
| `0x8500-0x851B` | HDMI 中断 (10 status + 10 mask) |
| `0x8520-0x8528` | HDMI 状态 (SYS_STATUS 等) |
| `0x8540-0x854A` | HDMI 控制 (DDC_CTL, HPD_CTL, INIT_END) |
| `0x8560-0x8843` | HDCP |
| `0x857A-0x857F` | 视频静音 |
| `0x8580-0x85CC` | 视频时序检测 |
| `0x85E0-0x85E4` | **EDID (MODE, LEN)** |
| `0x8600-0x8691` | 音频控制 + PLL |
| `0x8700-0x87EE` | InfoFrame 包 (AVI/AUD/SPD/VS/ACP/ISRC) |
| `0x8A00-0x8AB0` | 视频输出格式 |

### 9.2 关键寄存器位定义

#### ChipID `0x0000` (16-bit, RO)

| 位 | 名称 | 说明 |
|----|---|---|
| [15:8] | ChipID | 芯片 ID = `0x47` |
| [7:0] | RevID | 版本号 |

#### SysCtl `0x0002` (16-bit, R/W)

| 位 | 名称 | 说明 |
|----|---|---|
| [13] | ABRst | Audio Buffer 复位 |
| [11] | SPLRst | Splitter 复位 |
| [10] | IRRst | IR 复位 |
| [9] | CecRst | CEC 复位 |
| [8] | CTxRst | CSI/DSI TX 复位 |
| [7] | HdmiRst | HDMI Rx 复位 |
| [6] | I2S_Dis | I2S 禁用 |
| [0] | **SLEEP** | 1=进入睡眠 |

> 上电: `0x3F01` → 1ms → `0x0000`

#### ConfCtl0 `0x0004` (16-bit, R/W)

| 位 | 名称 | 说明 |
|----|---|---|
| [3] | I2Sdlyopt | I2S 延时选项 |
| [2] | **AutoIndex** | 1=I2C 地址自增 |
| [1] | **Vtx1_en** | 1=使能 DSI1 输出 |
| [0] | **Vtx0_en** | 1=使能 DSI0 输出 |

#### ConfCtl1 `0x0006` (16-bit, R/W)

| 位 | 名称 | 说明 |
|----|---|---|
| [3] | **dcs_clks** | 1=PCLK 未就绪时用 REFCLK |

#### PHY_CTL `0x8410` (8-bit)

| 位 | 名称 | 说明 |
|----|---|---|
| [0] | **PHYCtl** | 0=Host Manual, 1=Auto |

#### PHY_ENB `0x8413` (8-bit)

| 位 | 名称 | 说明 |
|----|---|---|
| [0] | **PHYEnb** | 1=退出 Suspend (默认 0x3E，`|=0x01` 写回) |

#### PHY_RSTX `0x8414` (8-bit)

| 位 | 名称 | 说明 |
|----|---|---|
| [0] | PHY_RSTX | 1=释放 HDMI PHY 复位 |

#### DDCIO_CTL `0x84F4` (8-bit)

| 位 | 名称 | 说明 |
|----|---|---|
| [0] | **DDCPWR** | 0=Power Down, 1=Normal |

#### APLL_CTL `0x84F0` (8-bit)

| 位 | 名称 | 说明 |
|----|---|---|
| [0] | **APPL_ON** | 0=Audio PLL OFF, 1=ON |

#### SYS_FREQ `0x8540` (LSB) / `0x8541` (MSB)

```
SYS_FREQ = REFCLK(Hz) / 10000
40MHz → 4000 = 0x0FA0  (8540=0xA0, 8541=0x0F)
50MHz → 5000 = 0x1388  (默认值)
```

#### DDC_CTL `0x8543` (8-bit)

| 位 | 名称 | 说明 |
|----|---|---|
| [2] | **DDC_ACTION** | 1=INIT_END 触发 DDC 激活 |
| [1:0] | DDC5V_MODE | 防抖: 00=0ms, 01=2ms, 10=10ms, 11=100ms |

#### HPD_CTL `0x8544` (8-bit)

| 位 | 名称 | 说明 |
|----|---|---|
| [1] | HPD_CTL0 | 0=Manual mode, 1=Auto |
| [0] | **HPD_OUT0** | Manual 模式: 0=拉低, 1=拉高 HPDO |

#### INIT_END `0x854A` (8-bit)

| 位 | 名称 | 说明 |
|----|---|---|
| [0] | INIT_END | 写 `0x01` 完成初始化 |

#### SYS_STATUS `0x8520` (8-bit, RO)

| 位 | 名称 | 说明 |
|----|---|---|
| 7 | S_SYNC | 同步检测 |
| 6 | S_AVMUTE | 自动静音 |
| 5 | S_HDCP | HDCP 使能 |
| 4 | S_HDMI | HDMI 信号 (vs DVI) |
| 3 | **S_PHY_SCDT** | PHY 信号检测 (TMDS 锁定) |
| 2 | S_PHY_PLL | PHY PLL 锁定 |
| 1 | S_TMDS | TMDS 时钟检测 |
| 0 | **S_DDC5V** | +5V 已接通 |

#### VI_STATUS1 `0x8522` (8-bit, RO)

| 位 | 名称 | 说明 |
|----|---|---|
| [3] | GBD | 3D 检测 |
| [2:3] | Deep Color | 0=8bit, 1=10bit, 2=12bit, 3=16bit |
| [1] | CS_422 | YCbCr 4:2:2 |
| [0] | Interlace | 隔行扫描 |

#### EDID_MODE `0x85E0` (8-bit)

| 位 | 名称 | 说明 |
|----|---|---|
| [1:0] | EDID_MODE | `00`=DDC 直通 EEPROM / `01`=内 RAM+DDC2B / `1x`=内 RAM+E-DDC |

#### EDID_LEN1 `0x85E3` (8-bit) / EDID_LEN2 `0x85E4` (8-bit)

| 位 | 名称 | 说明 |
|----|---|---|
| [7:0] | EDID_LEN[7:0] | 数据长度低字节，0=不读, >0x400=限 1024 |
| [2:0] | EDID_LEN[10:8] | 数据长度高 3 位 |

#### VOUT_FMT `0x8A00` (8-bit)

| 位 | 名称 | 说明 |
|----|---|---|
| [4] | 422_SEL | 0=Normal, 1=HDMI Through |
| [1:0] | **VOUT_SEL** | `00`=444/RGB, `01`=422, `1x`=Through |

#### VOUT_CSC `0x8A08` (8-bit)

| 位 | 名称 | 说明 |
|----|---|---|
| [6:4] | **VOUT_COLOR_SEL** | `000`=RGB Full, `001`=RGB Limited, `010-101`=YCbCr |
| [1:0] | **CSC_Mode** | `00`=CSC OFF, `01`=CSC ON, `10`=Auto, `11`=Host coeff |

### 9.3 MIPI_PLL_CONF `0x02AC` (32-bit)

```
bit[17:16] MP_LBW     Loop BW: 00=25% 01=33% 10=50% 11=Max
bit[15:12] MP_PRD     输入分频 = PRD+1
bit[11:10] MP_FRS     后分频 2^FRS
bit[9]     MP_LFBREN  下限移除使能
bit[8:0]   MP_FBD     反馈分频 = FBD+1

dsitx_pll_clk = REFCLK × (FBD+1)/(PRD+1) × 1/2^FRS

800Mbps: FBD=319, PRD=7, FRS=2, LBW=11
→ 0x02AC={0x3F,0x79,0x03,0x00}
```

### 9.4 DSI LPTX 发包 (发送 DCS 命令)

```
LPTX_TYPE        (0x022C) = 0x00000384   // Trigger0, LPDT=1, ALL lanes
DSI_LPTX_PKT_HDR (0x0230) = 0x10FF0015   // DT=0x15, cmd=0xFF, param=0x10
DSI_LPTX_REQ     (0x0228) = 0x01         // 触发
while(!(read(0x0220) & 0x01));           // 等完成
```

### 9.5 Splitter (0x5000-0x5094)

#### STX0_FPX `0x500C` / STX1_FPX `0x508C`

| 位 | 名称 | 说明 |
|----|---|---|
| [15] | stx_ehw | 0=Manual (精确像素), 1=Auto (自动切半) |
| [14] | stx_Tx1sel | 0=STX0 前半 STX1 后半, 1=反转 |
| [11:0] | stx0_fpxv | STX0 起始像素 (0-4095) |

#### STX0_LPX `0x500E` / STX1_LPX `0x508E`

| 位 | 名称 | 说明 |
|----|---|---|
| [11:0] | stx0_lpxv | STX0 结束像素 (0-4095) |

### 9.6 MODE_CONFIG `0x0110` (32-bit, DSI0)

| 位 | 名称 | 说明 |
|----|---|---|
| [4] | IndMode | 0=HS 命令, 1=LP 命令 |
| [2] | HSYNC_POL_SW | 1=Active Low (DSI 要求) |
| [1] | VSYNC_POL_SW | 1=Active Low (DSI 要求) |

### 9.7 FUNC_MODE `0x0150` (32-bit)

| 位 | 名称 | 说明 |
|----|---|---|
| [5] | HsCkMd | 0=非连续时钟, 1=连续时钟 |
| [0] | EoTpEn | 1=生成 EoT 包 |

### 9.8 DSITX_MODE `0x017C` (32-bit)

| 位 | 名称 | 说明 |
|----|---|---|
| [7] | BlankPkt_En | 0=LP 消隐, 1=HS blanking 包 |
| [0] | DSITXMd | 0=Pulse Mode, 1=Event Mode |

### 9.9 DSI 时序 (DSI0)

| 地址 | 名称 | 说明 |
|---|---|---|
| `0x018C` | DSI_HSYNC_WIDTH | HSA 字节数 |
| `0x0190` | DSI_HBPR | HBP 字节数 |
| `0x0108` | DSITX_CLKEN | DSI 时钟使能 |
| `0x0118` | LANE_ENABLE | Lane 使能: bit0=CK, bit1-4=D0-D3 |
| `0x011C` | DSITX_START | 写 1 启动传输 |
| `0x0284` | PPI_DPHY_POWERCNTRL | D-PHY 电源控制 |

### 9.10 初始化序列 (诱骗器模式)

```
1. SYSCTL     (0x0002) = 0x3F01   // 全复位+SLEEP
2. SYSCTL     (0x0002) = 0x0000   // 释放
3. ConfCtl0   (0x0004) = 0x0004   // AutoIndex=1
4. ConfCtl1   (0x0006) = 0x0008   // dcs_clks=1
5. SYS_FREQ0  (0x8540) → REFCLK/10000 LSB
6. SYS_FREQ1  (0x8541) → REFCLK/10000 MSB
7. EDID_MODE  (0x85E0) = 0x00     // 外挂EEPROM模式
8. DDCIO_CTL  (0x84F4): 0→1      // DDCIO 上电
9. DDC_CTL    (0x8543) = 0x04     // DDC_ACTION=1
10. PHY_ENB   (0x8413) |= 0x01    // 退出 Suspend
11. PHY_RSTX  (0x8414) |= 0x01    // 退出复位
12. VOUT_FMT  (0x8A00) = 0x00     // RGB
13. VOUT_CSC  (0x8A08) = 0x00     // 无转换
14. ConfCtl0  (0x0004) = 0x0007   // Vtx0_en+Vtx1_en+AutoIndex
15. INIT_END  (0x854A) = 0x01     // 初始化完成
16. HPD_CTL   (0x8544) = 0x01     // HPDO=H, 通知源端
```

## 10. 封装

| 参数 | 值 |
|---|-----|
| 封装 | VFBGA80 |
| 尺寸 | 7.0×7.0mm |
| 球间距 | 0.5mm |
| 球径 | 0.3mm |

## 11. 参考

- 数据手册：`Chip_IC_TC358870_VideoInterface.PDF` (Rev 1.53, 2017-10-25, 21 页)
- 寄存器手册：`TC358870XBG_rev1.3.pdf` (311 页编程指南)

- 接口存储 · [[LS029B3SX01]] · 视频显示/MIPI DSI · 视频显示/HDMI 协议概述 · 数字音频接口 I2S · 视频桥接芯片选型 · [[TC358870 Demo]]

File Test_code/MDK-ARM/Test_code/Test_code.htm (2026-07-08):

# Static Call Graph for image Test_code\Test_code.axf

#<CALLGRAPH># ARM Linker, 5050106: Last Updated: Wed Jul 08 17:05:33 2026

### Maximum Stack Usage = 448 bytes + Unknown(Functions without stacksize, Cycles, Untraceable Function Pointers)

### Call chain for Maximum Stack Depth:

__rt_entry_main ⇒ main ⇒ EDID_Init ⇒ EDID_Write ⇒ AT24C02_Write ⇒ AT24C02_WriteByte ⇒ HAL_I2C_Mem_Write ⇒ I2C_RequestMemoryWrite ⇒ I2C_WaitOnMasterAddressFlagUntilTimeout

### Functions with no stack information

- __user_initial_stackheap

### Mutually Recursive functions

- ADC1_2_IRQHandler ⇒ ADC1_2_IRQHandler

### Function Pointers

- ADC1_2_IRQHandler from startup_stm32f103xe.o(.text) referenced from startup_stm32f103xe.o(RESET)
- ADC3_IRQHandler from startup_stm32f103xe.o(.text) referenced from startup_stm32f103xe.o(RESET)
- BusFault_Handler from stm32f1xx_it.o(i.BusFault_Handler) referenced from startup_stm32f103xe.o(RESET)
- CAN1_RX1_IRQHandler from startup_stm32f103xe.o(.text) referenced from startup_stm32f103xe.o(RESET)
- CAN1_SCE_IRQHandler from startup_stm32f103xe.o(.text) referenced from startup_stm32f103xe.o(RESET)
- DMA1_Channel1_IRQHandler from startup_stm32f103xe.o(.text) referenced from startup_stm32f103xe.o(RESET)
- DMA1_Channel2_IRQHandler from startup_stm32f103xe.o(.text) referenced from startup_stm32f103xe.o(RESET)
- DMA1_Channel3_IRQHandler from startup_stm32f103xe.o(.text) referenced from startup_stm32f103xe.o(RESET)
- DMA1_Channel4_IRQHandler from startup_stm32f103xe.o(.text) referenced from startup_stm32f103xe.o(RESET)
- DMA1_Channel5_IRQHandler from startup_stm32f103xe.o(.text) referenced from startup_stm32f103xe.o(RESET)
- DMA1_Channel6_IRQHandler from startup_stm32f103xe.o(.text) referenced from startup_stm32f103xe.o(RESET)
- DMA1_Channel7_IRQHandler from startup_stm32f103xe.o(.text) referenced from startup_stm32f103xe.o(RESET)
- DMA2_Channel1_IRQHandler from startup_stm32f103xe.o(.text) referenced from startup_stm32f103xe.o(RESET)
- DMA2_Channel2_IRQHandler from startup_stm32f103xe.o(.text) referenced from startup_stm32f103xe.o(RESET)
- DMA2_Channel3_IRQHandler from startup_stm32f103xe.o(.text) referenced from startup_stm32f103xe.o(RESET)
- DMA2_Channel4_5_IRQHandler from startup_stm32f103xe.o(.text) referenced from startup_stm32f103xe.o(RESET)
- DebugMon_Handler from stm32f1xx_it.o(i.DebugMon_Handler) referenced from startup_stm32f103xe.o(RESET)
- EXTI0_IRQHandler from startup_stm32f103xe.o(.text) referenced from startup_stm32f103xe.o(RESET)
- EXTI15_10_IRQHandler from startup_stm32f103xe.o(.text) referenced from startup_stm32f103xe.o(RESET)
- EXTI1_IRQHandler from startup_stm32f103xe.o(.text) referenced from startup_stm32f103xe.o(RESET)
- EXTI2_IRQHandler from startup_stm32f103xe.o(.text) referenced from startup_stm32f103xe.o(RESET)
- EXTI3_IRQHandler from startup_stm32f103xe.o(.text) referenced from startup_stm32f103xe.o(RESET)
- EXTI4_IRQHandler from startup_stm32f103xe.o(.text) referenced from startup_stm32f103xe.o(RESET)
- EXTI9_5_IRQHandler from startup_stm32f103xe.o(.text) referenced from startup_stm32f103xe.o(RESET)
- FLASH_IRQHandler from startup_stm32f103xe.o(.text) referenced from startup_stm32f103xe.o(RESET)
- FSMC_IRQHandler from startup_stm32f103xe.o(.text) referenced from startup_stm32f103xe.o(RESET)
- HardFault_Handler from stm32f1xx_it.o(i.HardFault_Handler) referenced from startup_stm32f103xe.o(RESET)
- I2C1_ER_IRQHandler from startup_stm32f103xe.o(.text) referenced from startup_stm32f103xe.o(RESET)
- I2C1_EV_IRQHandler from startup_stm32f103xe.o(.text) referenced from startup_stm32f103xe.o(RESET)
- I2C2_ER_IRQHandler from startup_stm32f103xe.o(.text) referenced from startup_stm32f103xe.o(RESET)
- I2C2_EV_IRQHandler from startup_stm32f103xe.o(.text) referenced from startup_stm32f103xe.o(RESET)
- MemManage_Handler from stm32f1xx_it.o(i.MemManage_Handler) referenced from startup_stm32f103xe.o(RESET)
- NMI_Handler from stm32f1xx_it.o(i.NMI_Handler) referenced from startup_stm32f103xe.o(RESET)
- PVD_IRQHandler from startup_stm32f103xe.o(.text) referenced from startup_stm32f103xe.o(RESET)
- PendSV_Handler from stm32f1xx_it.o(i.PendSV_Handler) referenced from startup_stm32f103xe.o(RESET)
- RCC_IRQHandler from startup_stm32f103xe.o(.text) referenced from startup_stm32f103xe.o(RESET)
- RTC_Alarm_IRQHandler from startup_stm32f103xe.o(.text) referenced from startup_stm32f103xe.o(RESET)
- RTC_IRQHandler from startup_stm32f103xe.o(.text) referenced from startup_stm32f103xe.o(RESET)
- Reset_Handler from startup_stm32f103xe.o(.text) referenced from startup_stm32f103xe.o(RESET)
- SDIO_IRQHandler from startup_stm32f103xe.o(.text) referenced from startup_stm32f103xe.o(RESET)
- SPI1_IRQHandler from startup_stm32f103xe.o(.text) referenced from startup_stm32f103xe.o(RESET)
- SPI2_IRQHandler from startup_stm32f103xe.o(.text) referenced from startup_stm32f103xe.o(RESET)
- SPI3_IRQHandler from startup_stm32f103xe.o(.text) referenced from startup_stm32f103xe.o(RESET)
- SVC_Handler from stm32f1xx_it.o(i.SVC_Handler) referenced from startup_stm32f103xe.o(RESET)
- SysTick_Handler from stm32f1xx_it.o(i.SysTick_Handler) referenced from startup_stm32f103xe.o(RESET)
- SystemInit from system_stm32f1xx.o(i.SystemInit) referenced from startup_stm32f103xe.o(.text)
- TAMPER_IRQHandler from startup_stm32f103xe.o(.text) referenced from startup_stm32f103xe.o(RESET)
- TIM1_BRK_IRQHandler from startup_stm32f103xe.o(.text) referenced from startup_stm32f103xe.o(RESET)
- TIM1_CC_IRQHandler from startup_stm32f103xe.o(.text) referenced from startup_stm32f103xe.o(RESET)
- TIM1_TRG_COM_IRQHandler from startup_stm32f103xe.o(.text) referenced from startup_stm32f103xe.o(RESET)
- TIM1_UP_IRQHandler from startup_stm32f103xe.o(.text) referenced from startup_stm32f103xe.o(RESET)
- TIM2_IRQHandler from startup_stm32f103xe.o(.text) referenced from startup_stm32f103xe.o(RESET)
- TIM3_IRQHandler from startup_stm32f103xe.o(.text) referenced from startup_stm32f103xe.o(RESET)
- TIM4_IRQHandler from startup_stm32f103xe.o(.text) referenced from startup_stm32f103xe.o(RESET)
- TIM5_IRQHandler from startup_stm32f103xe.o(.text) referenced from startup_stm32f103xe.o(RESET)
- TIM6_IRQHandler from startup_stm32f103xe.o(.text) referenced from startup_stm32f103xe.o(RESET)
- TIM7_IRQHandler from startup_stm32f103xe.o(.text) referenced from startup_stm32f103xe.o(RESET)
- TIM8_BRK_IRQHandler from startup_stm32f103xe.o(.text) referenced from startup_stm32f103xe.o(RESET)
- TIM8_CC_IRQHandler from startup_stm32f103xe.o(.text) referenced from startup_stm32f103xe.o(RESET)
- TIM8_TRG_COM_IRQHandler from startup_stm32f103xe.o(.text) referenced from startup_stm32f103xe.o(RESET)
- TIM8_UP_IRQHandler from startup_stm32f103xe.o(.text) referenced from startup_stm32f103xe.o(RESET)
- UART4_IRQHandler from startup_stm32f103xe.o(.text) referenced from startup_stm32f103xe.o(RESET)
- UART5_IRQHandler from startup_stm32f103xe.o(.text) referenced from startup_stm32f103xe.o(RESET)
- USART1_IRQHandler from startup_stm32f103xe.o(.text) referenced from startup_stm32f103xe.o(RESET)
- USART2_IRQHandler from startup_stm32f103xe.o(.text) referenced from startup_stm32f103xe.o(RESET)
- USART3_IRQHandler from startup_stm32f103xe.o(.text) referenced from startup_stm32f103xe.o(RESET)
- USBWakeUp_IRQHandler from startup_stm32f103xe.o(.text) referenced from startup_stm32f103xe.o(RESET)
- USB_HP_CAN1_TX_IRQHandler from startup_stm32f103xe.o(.text) referenced from startup_stm32f103xe.o(RESET)
- USB_LP_CAN1_RX0_IRQHandler from startup_stm32f103xe.o(.text) referenced from startup_stm32f103xe.o(RESET)
- UsageFault_Handler from stm32f1xx_it.o(i.UsageFault_Handler) referenced from startup_stm32f103xe.o(RESET)
- WWDG_IRQHandler from startup_stm32f103xe.o(.text) referenced from startup_stm32f103xe.o(RESET)
- __main from __main.o(!!!main) referenced from startup_stm32f103xe.o(.text)

### Global Symbols

__main (Thumb, 8 bytes, Stack size 0 bytes, __main.o(!!!main))

[Calls]

- >> __scatterload
- >> __rt_entry

__scatterload (Thumb, 0 bytes, Stack size unknown bytes, __scatter.o(!!!scatter))

[Called By]

- >> __main

__scatterload_rt2 (Thumb, 44 bytes, Stack size unknown bytes, __scatter.o(!!!scatter), UNUSED)

[Calls]

- >> __rt_entry

__scatterload_rt2_thumb_only (Thumb, 0 bytes, Stack size unknown bytes, __scatter.o(!!!scatter), UNUSED)

__scatterload_null (Thumb, 0 bytes, Stack size unknown bytes, __scatter.o(!!!scatter), UNUSED)

__scatterload_copy (Thumb, 26 bytes, Stack size unknown bytes, __scatter_copy.o(!!handler_copy), UNUSED)

[Calls]

- >> __scatterload_copy

[Called By]

- >> __scatterload_copy

__scatterload_zeroinit (Thumb, 28 bytes, Stack size unknown bytes, __scatter_zi.o(!!handler_zi), UNUSED)

__rt_lib_init (Thumb, 0 bytes, Stack size unknown bytes, libinit.o(.ARM.Collect$$libinit$$00000000))

[Called By]

- >> __rt_entry_li

__rt_lib_init_alloca_1 (Thumb, 0 bytes, Stack size unknown bytes, libinit2.o(.ARM.Collect$$libinit$$0000002E))

__rt_lib_init_argv_1 (Thumb, 0 bytes, Stack size unknown bytes, libinit2.o(.ARM.Collect$$libinit$$0000002C))

__rt_lib_init_atexit_1 (Thumb, 0 bytes, Stack size unknown bytes, libinit2.o(.ARM.Collect$$libinit$$0000001B))

__rt_lib_init_clock_1 (Thumb, 0 bytes, Stack size unknown bytes, libinit2.o(.ARM.Collect$$libinit$$00000021))

__rt_lib_init_cpp_1 (Thumb, 0 bytes, Stack size unknown bytes, libinit2.o(.ARM.Collect$$libinit$$00000032))

__rt_lib_init_exceptions_1 (Thumb, 0 bytes, Stack size unknown bytes, libinit2.o(.ARM.Collect$$libinit$$00000030))

__rt_lib_init_fp_1 (Thumb, 0 bytes, Stack size unknown bytes, libinit2.o(.ARM.Collect$$libinit$$00000002))

__rt_lib_init_fp_trap_1 (Thumb, 0 bytes, Stack size unknown bytes, libinit2.o(.ARM.Collect$$libinit$$0000001F))

__rt_lib_init_getenv_1 (Thumb, 0 bytes, Stack size unknown bytes, libinit2.o(.ARM.Collect$$libinit$$00000023))

__rt_lib_init_heap_1 (Thumb, 0 bytes, Stack size unknown bytes, libinit2.o(.ARM.Collect$$libinit$$0000000A))

__rt_lib_init_lc_collate_1 (Thumb, 0 bytes, Stack size unknown bytes, libinit2.o(.ARM.Collect$$libinit$$00000011))

__rt_lib_init_lc_ctype_1 (Thumb, 0 bytes, Stack size unknown bytes, libinit2.o(.ARM.Collect$$libinit$$00000013))

__rt_lib_init_lc_monetary_1 (Thumb, 0 bytes, Stack size unknown bytes, libinit2.o(.ARM.Collect$$libinit$$00000015))

__rt_lib_init_lc_numeric_1 (Thumb, 0 bytes, Stack size unknown bytes, libinit2.o(.ARM.Collect$$libinit$$00000017))

__rt_lib_init_lc_time_1 (Thumb, 0 bytes, Stack size unknown bytes, libinit2.o(.ARM.Collect$$libinit$$00000019))

__rt_lib_init_preinit_1 (Thumb, 0 bytes, Stack size unknown bytes, libinit2.o(.ARM.Collect$$libinit$$00000004))

__rt_lib_init_rand_1 (Thumb, 0 bytes, Stack size unknown bytes, libinit2.o(.ARM.Collect$$libinit$$0000000E))

__rt_lib_init_return (Thumb, 0 bytes, Stack size unknown bytes, libinit2.o(.ARM.Collect$$libinit$$00000033))

__rt_lib_init_signal_1 (Thumb, 0 bytes, Stack size unknown bytes, libinit2.o(.ARM.Collect$$libinit$$0000001D))

__rt_lib_init_stdio_1 (Thumb, 0 bytes, Stack size unknown bytes, libinit2.o(.ARM.Collect$$libinit$$00000025))

__rt_lib_init_user_alloc_1 (Thumb, 0 bytes, Stack size unknown bytes, libinit2.o(.ARM.Collect$$libinit$$0000000C))

__rt_lib_shutdown (Thumb, 0 bytes, Stack size unknown bytes, libshutdown.o(.ARM.Collect$$libshutdown$$00000000))

[Called By]

- >> __rt_exit_ls

__rt_lib_shutdown_fp_trap_1 (Thumb, 0 bytes, Stack size unknown bytes, libshutdown2.o(.ARM.Collect$$libshutdown$$00000006))

__rt_lib_shutdown_heap_1 (Thumb, 0 bytes, Stack size unknown bytes, libshutdown2.o(.ARM.Collect$$libshutdown$$0000000E))

__rt_lib_shutdown_return (Thumb, 0 bytes, Stack size unknown bytes, libshutdown2.o(.ARM.Collect$$libshutdown$$0000000F))

__rt_lib_shutdown_signal_1 (Thumb, 0 bytes, Stack size unknown bytes, libshutdown2.o(.ARM.Collect$$libshutdown$$00000009))

__rt_lib_shutdown_stdio_1 (Thumb, 0 bytes, Stack size unknown bytes, libshutdown2.o(.ARM.Collect$$libshutdown$$00000003))

__rt_lib_shutdown_user_alloc_1 (Thumb, 0 bytes, Stack size unknown bytes, libshutdown2.o(.ARM.Collect$$libshutdown$$0000000B))

__rt_entry (Thumb, 0 bytes, Stack size unknown bytes, __rtentry.o(.ARM.Collect$$rtentry$$00000000))

[Called By]

- >> __scatterload_rt2
- >> __main

__rt_entry_presh_1 (Thumb, 0 bytes, Stack size unknown bytes, __rtentry2.o(.ARM.Collect$$rtentry$$00000002))

__rt_entry_sh (Thumb, 0 bytes, Stack size unknown bytes, __rtentry4.o(.ARM.Collect$$rtentry$$00000004))

[Stack]

- Max Depth = 8 + Unknown Stack Size
- Call Chain = __rt_entry_sh ⇒ __user_setup_stackheap

[Calls]

- >> __user_setup_stackheap

__rt_entry_li (Thumb, 0 bytes, Stack size unknown bytes, __rtentry2.o(.ARM.Collect$$rtentry$$0000000A))

[Calls]

- >> __rt_lib_init

__rt_entry_postsh_1 (Thumb, 0 bytes, Stack size unknown bytes, __rtentry2.o(.ARM.Collect$$rtentry$$00000009))

__rt_entry_main (Thumb, 0 bytes, Stack size unknown bytes, __rtentry2.o(.ARM.Collect$$rtentry$$0000000D))

[Stack]

- Max Depth = 448 + Unknown Stack Size
- Call Chain = __rt_entry_main ⇒ main ⇒ EDID_Init ⇒ EDID_Write ⇒ AT24C02_Write ⇒ AT24C02_WriteByte ⇒ HAL_I2C_Mem_Write ⇒ I2C_RequestMemoryWrite ⇒ I2C_WaitOnMasterAddressFlagUntilTimeout

[Calls]

- >> main
- >> exit

__rt_entry_postli_1 (Thumb, 0 bytes, Stack size unknown bytes, __rtentry2.o(.ARM.Collect$$rtentry$$0000000C))

__rt_exit (Thumb, 0 bytes, Stack size unknown bytes, rtexit.o(.ARM.Collect$$rtexit$$00000000))

[Called By]

- >> exit

__rt_exit_ls (Thumb, 0 bytes, Stack size unknown bytes, rtexit2.o(.ARM.Collect$$rtexit$$00000003))

[Calls]

- >> __rt_lib_shutdown

__rt_exit_prels_1 (Thumb, 0 bytes, Stack size unknown bytes, rtexit2.o(.ARM.Collect$$rtexit$$00000002))

__rt_exit_exit (Thumb, 0 bytes, Stack size unknown bytes, rtexit2.o(.ARM.Collect$$rtexit$$00000004))

[Calls]

- >> _sys_exit

Reset_Handler (Thumb, 8 bytes, Stack size 0 bytes, startup_stm32f103xe.o(.text))
[Address Reference Count : 1]

- startup_stm32f103xe.o(RESET)

ADC1_2_IRQHandler (Thumb, 0 bytes, Stack size 0 bytes, startup_stm32f103xe.o(.text))

[Calls]

- >> ADC1_2_IRQHandler

[Called By]

- >> ADC1_2_IRQHandler

[Address Reference Count : 1]

- startup_stm32f103xe.o(RESET)

ADC3_IRQHandler (Thumb, 0 bytes, Stack size 0 bytes, startup_stm32f103xe.o(.text))
[Address Reference Count : 1]

- startup_stm32f103xe.o(RESET)

CAN1_RX1_IRQHandler (Thumb, 0 bytes, Stack size 0 bytes, startup_stm32f103xe.o(.text))
[Address Reference Count : 1]

- startup_stm32f103xe.o(RESET)

CAN1_SCE_IRQHandler (Thumb, 0 bytes, Stack size 0 bytes, startup_stm32f103xe.o(.text))
[Address Reference Count : 1]

- startup_stm32f103xe.o(RESET)

DMA1_Channel1_IRQHandler (Thumb, 0 bytes, Stack size 0 bytes, startup_stm32f103xe.o(.text))
[Address Reference Count : 1]

- startup_stm32f103xe.o(RESET)

DMA1_Channel2_IRQHandler (Thumb, 0 bytes, Stack size 0 bytes, startup_stm32f103xe.o(.text))
[Address Reference Count : 1]

- startup_stm32f103xe.o(RESET)

DMA1_Channel3_IRQHandler (Thumb, 0 bytes, Stack size 0 bytes, startup_stm32f103xe.o(.text))
[Address Reference Count : 1]

- startup_stm32f103xe.o(RESET)

DMA1_Channel4_IRQHandler (Thumb, 0 bytes, Stack size 0 bytes, startup_stm32f103xe.o(.text))
[Address Reference Count : 1]

- startup_stm32f103xe.o(RESET)

DMA1_Channel5_IRQHandler (Thumb, 0 bytes, Stack size 0 bytes, startup_stm32f103xe.o(.text))
[Address Reference Count : 1]

- startup_stm32f103xe.o(RESET)

DMA1_Channel6_IRQHandler (Thumb, 0 bytes, Stack size 0 bytes, startup_stm32f103xe.o(.text))
[Address Reference Count : 1]

- startup_stm32f103xe.o(RESET)

DMA1_Channel7_IRQHandler (Thumb, 0 bytes, Stack size 0 bytes, startup_stm32f103xe.o(.text))
[Address Reference Count : 1]

- startup_stm32f103xe.o(RESET)

DMA2_Channel1_IRQHandler (Thumb, 0 bytes, Stack size 0 bytes, startup_stm32f103xe.o(.text))
[Address Reference Count : 1]

- startup_stm32f103xe.o(RESET)

DMA2_Channel2_IRQHandler (Thumb, 0 bytes, Stack size 0 bytes, startup_stm32f103xe.o(.text))
[Address Reference Count : 1]

- startup_stm32f103xe.o(RESET)

DMA2_Channel3_IRQHandler (Thumb, 0 bytes, Stack size 0 bytes, startup_stm32f103xe.o(.text))
[Address Reference Count : 1]

- startup_stm32f103xe.o(RESET)

DMA2_Channel4_5_IRQHandler (Thumb, 0 bytes, Stack size 0 bytes, startup_stm32f103xe.o(.text))
[Address Reference Count : 1]

- startup_stm32f103xe.o(RESET)

EXTI0_IRQHandler (Thumb, 0 bytes, Stack size 0 bytes, startup_stm32f103xe.o(.text))
[Address Reference Count : 1]

- startup_stm32f103xe.o(RESET)

EXTI15_10_IRQHandler (Thumb, 0 bytes, Stack size 0 bytes, startup_stm32f103xe.o(.text))
[Address Reference Count : 1]

- startup_stm32f103xe.o(RESET)

EXTI1_IRQHandler (Thumb, 0 bytes, Stack size 0 bytes, startup_stm32f103xe.o(.text))
[Address Reference Count : 1]

- startup_stm32f103xe.o(RESET)

EXTI2_IRQHandler (Thumb, 0 bytes, Stack size 0 bytes, startup_stm32f103xe.o(.text))
[Address Reference Count : 1]

- startup_stm32f103xe.o(RESET)

EXTI3_IRQHandler (Thumb, 0 bytes, Stack size 0 bytes, startup_stm32f103xe.o(.text))
[Address Reference Count : 1]

- startup_stm32f103xe.o(RESET)

EXTI4_IRQHandler (Thumb, 0 bytes, Stack size 0 bytes, startup_stm32f103xe.o(.text))
[Address Reference Count : 1]

- startup_stm32f103xe.o(RESET)

EXTI9_5_IRQHandler (Thumb, 0 bytes, Stack size 0 bytes, startup_stm32f103xe.o(.text))
[Address Reference Count : 1]

- startup_stm32f103xe.o(RESET)

FLASH_IRQHandler (Thumb, 0 bytes, Stack size 0 bytes, startup_stm32f103xe.o(.text))
[Address Reference Count : 1]

- startup_stm32f103xe.o(RESET)

FSMC_IRQHandler (Thumb, 0 bytes, Stack size 0 bytes, startup_stm32f103xe.o(.text))
[Address Reference Count : 1]

- startup_stm32f103xe.o(RESET)

I2C1_ER_IRQHandler (Thumb, 0 bytes, Stack size 0 bytes, startup_stm32f103xe.o(.text))
[Address Reference Count : 1]

- startup_stm32f103xe.o(RESET)

I2C1_EV_IRQHandler (Thumb, 0 bytes, Stack size 0 bytes, startup_stm32f103xe.o(.text))
[Address Reference Count : 1]

- startup_stm32f103xe.o(RESET)

I2C2_ER_IRQHandler (Thumb, 0 bytes, Stack size 0 bytes, startup_stm32f103xe.o(.text))
[Address Reference Count : 1]

- startup_stm32f103xe.o(RESET)

I2C2_EV_IRQHandler (Thumb, 0 bytes, Stack size 0 bytes, startup_stm32f103xe.o(.text))
[Address Reference Count : 1]

- startup_stm32f103xe.o(RESET)

PVD_IRQHandler (Thumb, 0 bytes, Stack size 0 bytes, startup_stm32f103xe.o(.text))
[Address Reference Count : 1]

- startup_stm32f103xe.o(RESET)

RCC_IRQHandler (Thumb, 0 bytes, Stack size 0 bytes, startup_stm32f103xe.o(.text))
[Address Reference Count : 1]

- startup_stm32f103xe.o(RESET)

RTC_Alarm_IRQHandler (Thumb, 0 bytes, Stack size 0 bytes, startup_stm32f103xe.o(.text))
[Address Reference Count : 1]

- startup_stm32f103xe.o(RESET)

RTC_IRQHandler (Thumb, 0 bytes, Stack size 0 bytes, startup_stm32f103xe.o(.text))
[Address Reference Count : 1]

- startup_stm32f103xe.o(RESET)

SDIO_IRQHandler (Thumb, 0 bytes, Stack size 0 bytes, startup_stm32f103xe.o(.text))
[Address Reference Count : 1]

- startup_stm32f103xe.o(RESET)

SPI1_IRQHandler (Thumb, 0 bytes, Stack size 0 bytes, startup_stm32f103xe.o(.text))
[Address Reference Count : 1]

- startup_stm32f103xe.o(RESET)

SPI2_IRQHandler (Thumb, 0 bytes, Stack size 0 bytes, startup_stm32f103xe.o(.text))
[Address Reference Count : 1]

- startup_stm32f103xe.o(RESET)

SPI3_IRQHandler (Thumb, 0 bytes, Stack size 0 bytes, startup_stm32f103xe.o(.text))
[Address Reference Count : 1]

- startup_stm32f103xe.o(RESET)

TAMPER_IRQHandler (Thumb, 0 bytes, Stack size 0 bytes, startup_stm32f103xe.o(.text))
[Address Reference Count : 1]

- startup_stm32f103xe.o(RESET)

TIM1_BRK_IRQHandler (Thumb, 0 bytes, Stack size 0 bytes, startup_stm32f103xe.o(.text))
[Address Reference Count : 1]

- startup_stm32f103xe.o(RESET)

TIM1_CC_IRQHandler (Thumb, 0 bytes, Stack size 0 bytes, startup_stm32f103xe.o(.text))
[Address Reference Count : 1]

- startup_stm32f103xe.o(RESET)

TIM1_TRG_COM_IRQHandler (Thumb, 0 bytes, Stack size 0 bytes, startup_stm32f103xe.o(.text))
[Address Reference Count : 1]

- startup_stm32f103xe.o(RESET)

TIM1_UP_IRQHandler (Thumb, 0 bytes, Stack size 0 bytes, startup_stm32f103xe.o(.text))
[Address Reference Count : 1]

- startup_stm32f103xe.o(RESET)

TIM2_IRQHandler (Thumb, 0 bytes, Stack size 0 bytes, startup_stm32f103xe.o(.text))
[Address Reference Count : 1]

- startup_stm32f103xe.o(RESET)

TIM3_IRQHandler (Thumb, 0 bytes, Stack size 0 bytes, startup_stm32f103xe.o(.text))
[Address Reference Count : 1]

- startup_stm32f103xe.o(RESET)
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

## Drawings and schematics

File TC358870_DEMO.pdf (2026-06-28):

# Type-C Power IN

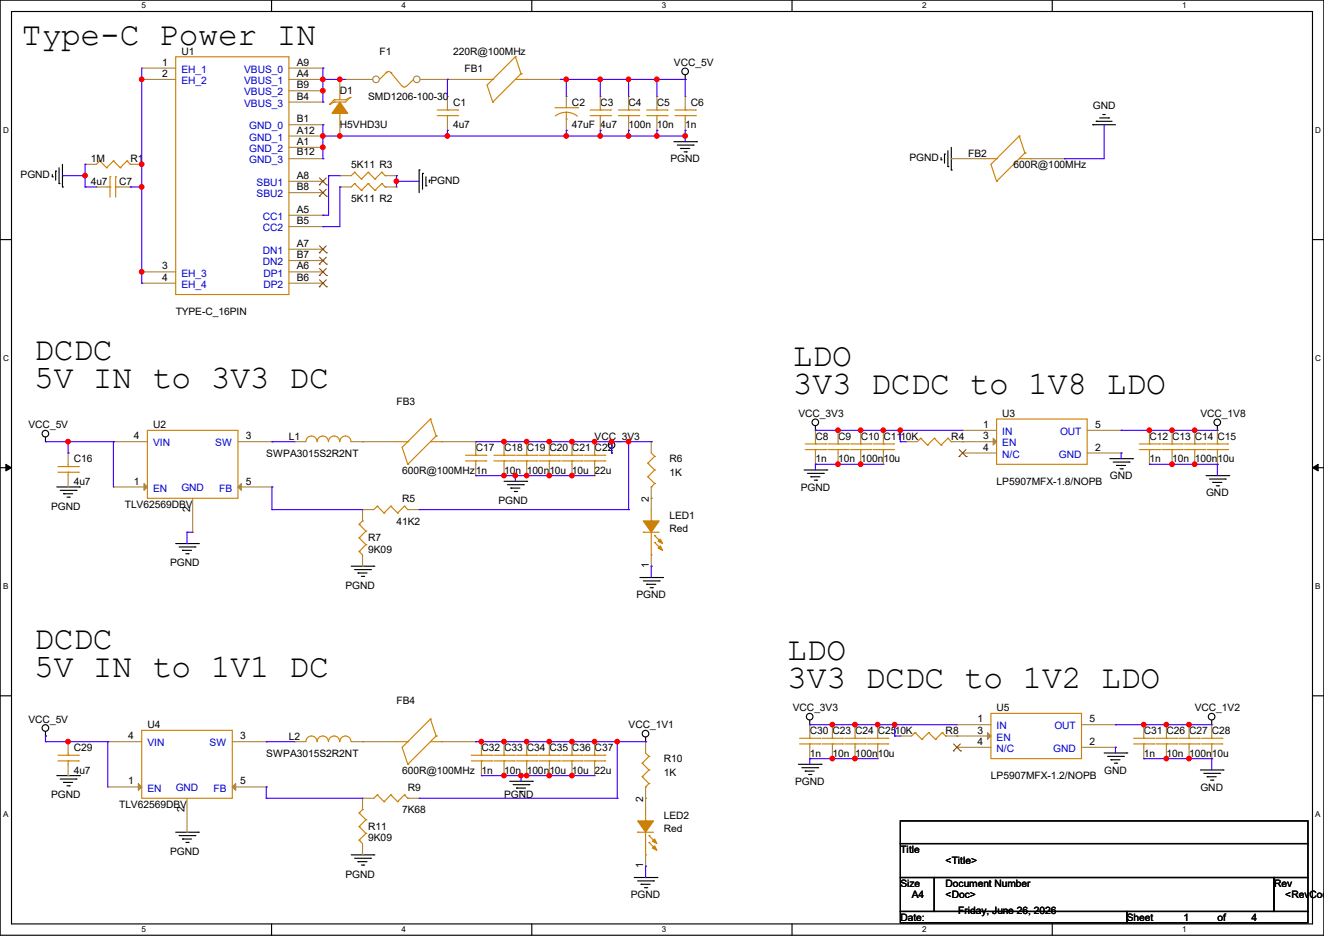
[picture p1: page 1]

# DCDC 3V3 DC to LED DC(22mA)

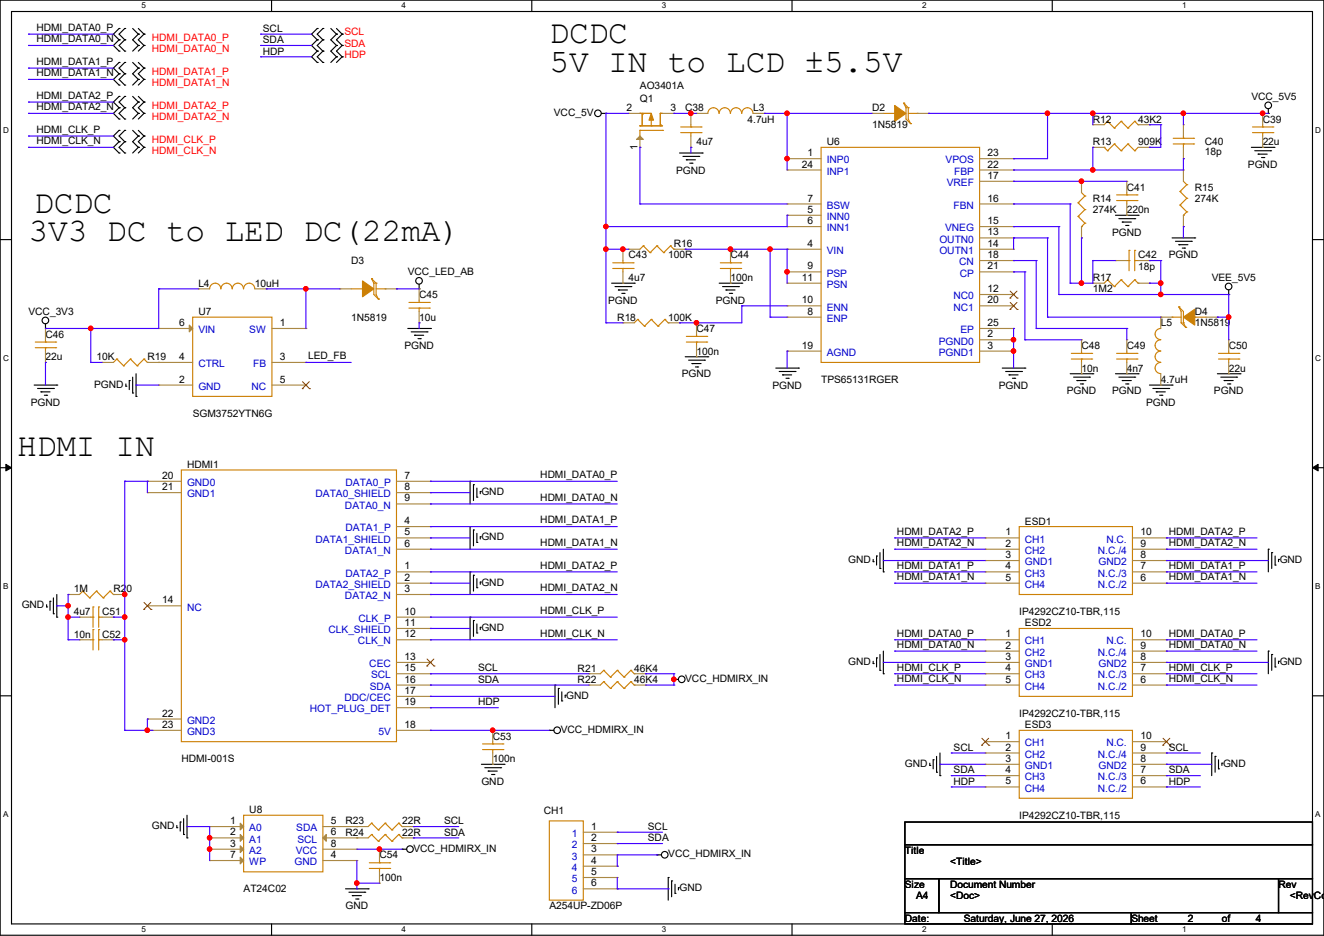
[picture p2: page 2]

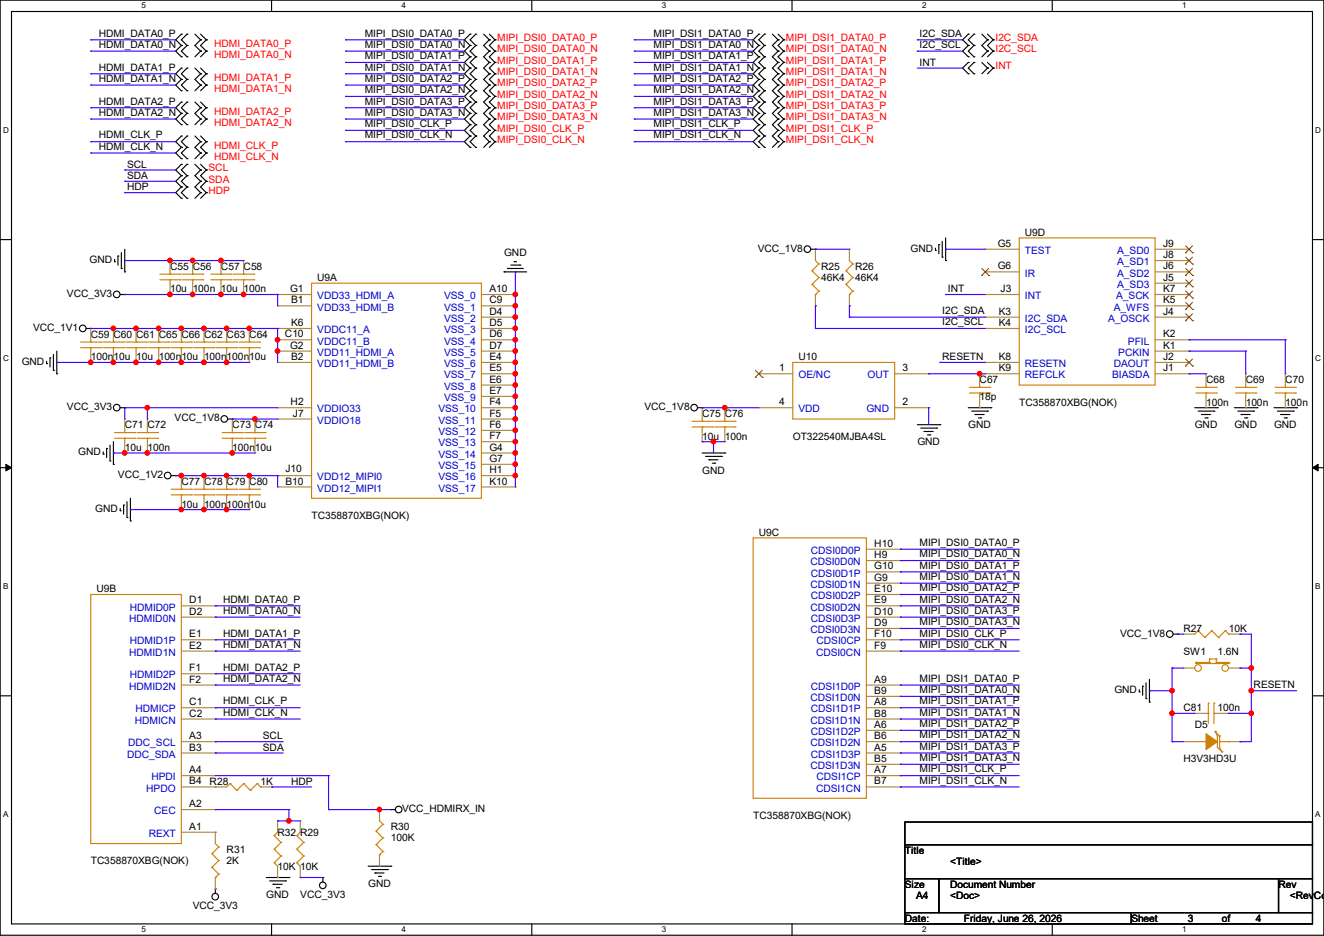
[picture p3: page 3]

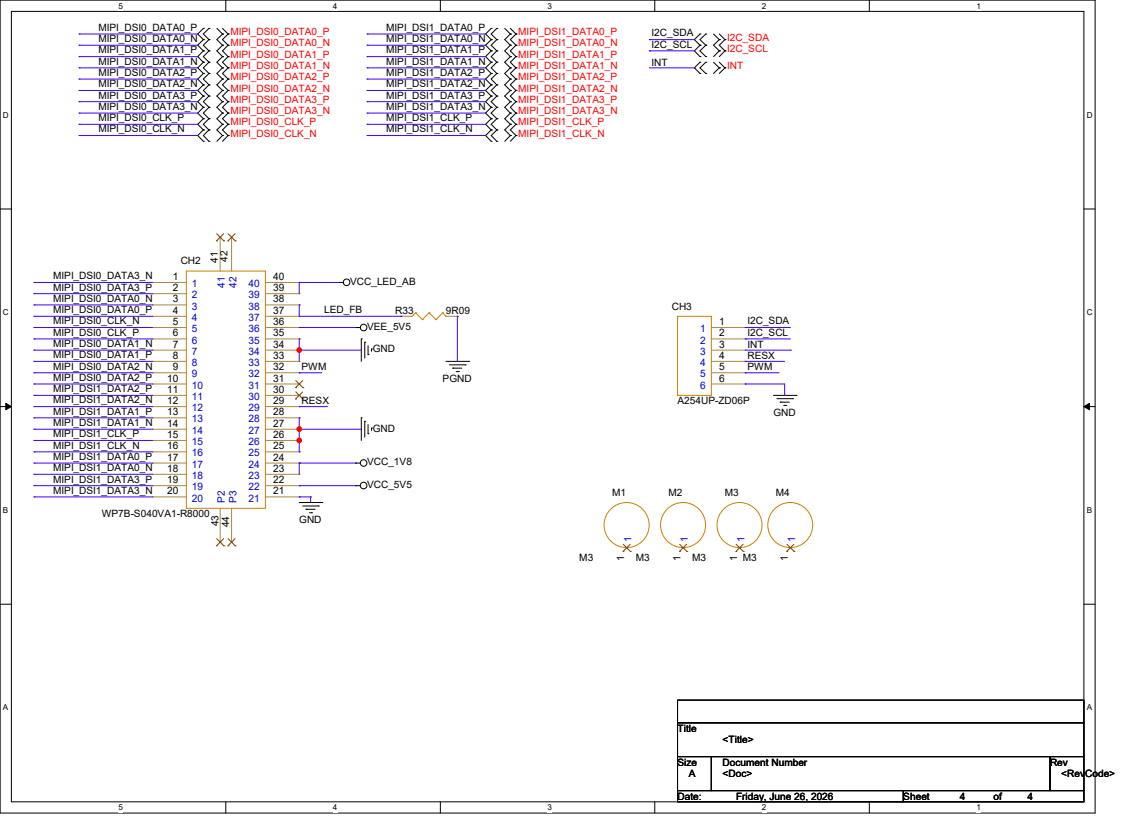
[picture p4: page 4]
GND; VCC_LED_AB; VEE_5V5; VCC_1V8; VCC_5V5; PGND; MIPI_DSI0_DATA0_P; MIPI_DSI1_DATA0_P; MIPI_DSI0_DATA0_N; MIPI_DSI1_DATA0_N; MIPI_DSI0_DATA1_P; MIPI_DSI1_DATA1_P; MIPI_DSI0_DATA1_N; MIPI_DSI1_DATA1_N; MIPI_DSI0_DATA2_P; MIPI_DSI1_DATA2_P; MIPI_DSI0_DATA2_N; MIPI_DSI1_DATA2_N; MIPI_DSI0_DATA3_P; MIPI_DSI1_DATA3_P; MIPI_DSI0_DATA3_N; MIPI_DSI1_DATA3_N; MIPI_DSI0_CLK_P; MIPI_DSI1_CLK_P; MIPI_DSI0_CLK_N; MIPI_DSI1_CLK_N; I2C_SDA I2C_SCL; INT; Title; <Title>; Friday, June 26, 2026; PWM; RESX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

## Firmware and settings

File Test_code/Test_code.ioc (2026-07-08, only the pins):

Mcu.UserName=STM32F103ZETx
PA13.Signal=SYS_JTMS-SWDIO
PA14.Signal=SYS_JTCK-SWCLK
PB10.Signal=I2C2_SCL
PB11.Signal=I2C2_SDA
PB3.Signal=SYS_JTDO-TRACESWO
PB6.Signal=I2C1_SCL
PB7.Signal=I2C1_SDA

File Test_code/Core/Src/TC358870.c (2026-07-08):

/**
 * @file    TC358870.c
 * @brief   TC358870XBG HDMI → MIPI DSI 桥接芯片 I2C 寄存器读写实现
 *
 * TC358870 寄存器地址为 16-bit (big-endian), 故采用 HAL_I2C_Master_Transmit
 * / Master_Receive 手动构造 I2C 帧, 而非 HAL_I2C_Mem_Write (仅支持 8-bit 地址)。
 *
 * 帧格式:
 *   Write: [RegAddr_H, RegAddr_L, Data ...]
 *   Read:  [RegAddr_H, RegAddr_L] → RESTART → [Data ...]
 */

#include "TC358870.h"

#define I2C_TIMEOUT            1000          /**< I2C 读写操作超时 (ms) */
#define MAX_RETRIES            3
#define ACK_POLL_TIMEOUT       5                 /**< ACK 轮询单次超时 (ms), TC358870 写周期 ≤5ms */


/**
 * @brief  写 8-bit 寄存器
 * @param  DevAddress  I2C 8-bit 设备地址 (TC358870_ADDRESS_Write = 0x1E)
 * @param  regAddr     16-bit 寄存器地址
 * @param  data        8-bit 写入值
 * @retval HAL_OK / HAL_ERROR / HAL_TIMEOUT
 */
HAL_StatusTypeDef TC358870_WriteReg_8Bit(uint16_t DevAddress, uint16_t regAddr, uint8_t data)
{
    uint8_t buffer[3];
    buffer[0] = (regAddr >> 8) & 0xFF; // 寄存器地址高字节
    buffer[1] = regAddr & 0xFF;        // 寄存器地址低字节
    buffer[2] = data;                  // 数据字节

    HAL_StatusTypeDef status = HAL_I2C_Master_Transmit(TC358870_I2C, DevAddress, buffer, sizeof(buffer), I2C_TIMEOUT);
    if (status != HAL_OK)
    {
        return status;
    }
    return status;
}


/**
 * @brief  读 8-bit 寄存器
 * @param  DevAddress  I2C 8-bit 设备地址
 * @param  regAddr     16-bit 寄存器地址
 * @param  data        读回数据存放指针
 * @retval HAL_OK / HAL_ERROR / HAL_TIMEOUT
 */
HAL_StatusTypeDef TC358870_ReadReg_8Bit(uint16_t DevAddress, uint16_t regAddr, uint8_t *data)
{
    uint8_t addrBuffer[2];
    addrBuffer[0] = (regAddr >> 8) & 0xFF; // 寄存器地址高字节
    addrBuffer[1] = regAddr & 0xFF;        // 寄存器地址低字节

    HAL_StatusTypeDef status = HAL_I2C_Master_Transmit(TC358870_I2C, DevAddress, addrBuffer, sizeof(addrBuffer), I2C_TIMEOUT);
    if (status != HAL_OK)
    {
        return status;
    }

    status = HAL_I2C_Master_Receive(TC358870_I2C, DevAddress, data, 1, I2C_TIMEOUT);
    return status;
}


/**
 * @brief  写 16-bit 寄存器 (big-endian)
 * @param  DevAddress  I2C 8-bit 设备地址
 * @param  regAddr     16-bit 寄存器地址
 * @param  data        16-bit 写入值 (高字节在前)
 * @retval HAL_OK / HAL_ERROR / HAL_TIMEOUT
 */
HAL_StatusTypeDef TC358870_WriteReg_16Bit(uint16_t DevAddress, uint16_t regAddr, uint16_t data)
{
    uint8_t buffer[4];
    buffer[0] = (regAddr >> 8) & 0xFF; // 寄存器地址高字节
    buffer[1] = regAddr & 0xFF;        // 寄存器地址低字节
    buffer[2] = (data >> 8) & 0xFF;    // 数据高字节
    buffer[3] = data & 0xFF;           // 数据低字节

    HAL_StatusTypeDef status = HAL_I2C_Master_Transmit(TC358870_I2C, DevAddress, buffer, sizeof(buffer), I2C_TIMEOUT);
    if (status != HAL_OK)
    {
        return status;
    }
    return status;
}


/**
 * @brief  读 16-bit 寄存器 (big-endian)
 * @param  DevAddress  I2C 8-bit 设备地址
 * @param  regAddr     16-bit 寄存器地址
 * @param  data        读回数据存放指针 (低 16-bit 有效)
 * @retval HAL_OK / HAL_ERROR / HAL_TIMEOUT
 */
HAL_StatusTypeDef TC358870_ReadReg_16Bit(uint16_t DevAddress, uint16_t regAddr, uint16_t *data)
{
    uint8_t addrBuffer[2];
    addrBuffer[0] = (regAddr >> 8) & 0xFF; // 寄存器地址高字节
    addrBuffer[1] = regAddr & 0xFF;        // 寄存器地址低字节

    HAL_StatusTypeDef status = HAL_I2C_Master_Transmit(TC358870_I2C, DevAddress, addrBuffer, sizeof(addrBuffer), I2C_TIMEOUT);
    if (status != HAL_OK)
    {
        return status;
    }

    uint8_t dataBuffer[2];
    status = HAL_I2C_Master_Receive(TC358870_I2C, DevAddress, dataBuffer, sizeof(dataBuffer), I2C_TIMEOUT);
    if (status != HAL_OK)
    {
        return status;
    }

    *data = (dataBuffer[0] << 8) | dataBuffer[1]; // MSB:LSB → uint16_t
    return status;
}


/**
 * @brief  写 32-bit 寄存器 (big-endian)
 * @param  DevAddress  I2C 8-bit 设备地址
 * @param  regAddr     16-bit 寄存器地址
 * @param  data        32-bit 写入值 (高字节在前)
 * @retval HAL_OK / HAL_ERROR / HAL_TIMEOUT
 *
 * @note   TC358870 实际没有 32-bit 寄存器, 保留为 API 完整性。
 *         如需写入连续两个 16-bit 寄存器, 可连续调用 WriteReg_16Bit。
 */
HAL_StatusTypeDef TC358870_WriteReg_32Bit(uint16_t DevAddress, uint16_t regAddr, uint32_t data)
{
    uint8_t buffer[6];
    buffer[0] = (regAddr >> 8) & 0xFF; // 寄存器地址高字节
    buffer[1] = regAddr & 0xFF;        // 寄存器地址低字节
    buffer[2] = (data >> 24) & 0xFF;   // 数据最高字节
    buffer[3] = (data >> 16) & 0xFF;   // 数据次高字节
    buffer[4] = (data >> 8) & 0xFF;    // 数据次低字节
    buffer[5] = data & 0xFF;           // 数据最低字节

    HAL_StatusTypeDef status = HAL_I2C_Master_Transmit(TC358870_I2C, DevAddress, buffer, sizeof(buffer), I2C_TIMEOUT);
    if (status != HAL_OK)
    {
        return status;
    }
    return status;
}


/**
 * @brief  读 32-bit 寄存器 (big-endian)
 * @param  DevAddress  I2C 8-bit 设备地址
 * @param  regAddr     16-bit 寄存器地址
 * @param  data        读回数据存放指针
 * @retval HAL_OK / HAL_ERROR / HAL_TIMEOUT
 *
 * @note   同上, TC358870 无 32-bit 寄存器, 保留为 API 完整性。
 */
HAL_StatusTypeDef TC358870_ReadReg_32Bit(uint16_t DevAddress, uint16_t regAddr, uint32_t *data)
{
    uint8_t addrBuffer[2];
    addrBuffer[0] = (regAddr >> 8) & 0xFF; // 寄存器地址高字节
    addrBuffer[1] = regAddr & 0xFF;        // 寄存器地址低字节

    HAL_StatusTypeDef status = HAL_I2C_Master_Transmit(TC358870_I2C, DevAddress, addrBuffer, sizeof(addrBuffer), I2C_TIMEOUT);
    if (status != HAL_OK)
    {
        return status;
    }

    uint8_t dataBuffer[4];
    status = HAL_I2C_Master_Receive(TC358870_I2C, DevAddress, dataBuffer, sizeof(dataBuffer), I2C_TIMEOUT);
    if (status != HAL_OK)
    {
        return status;
    }

    // MSB first → uint32_t
    *data = (uint32_t)dataBuffer[0] << 24
          | (uint32_t)dataBuffer[1] << 16
          | (uint32_t)dataBuffer[2] << 8
          | (uint32_t)dataBuffer[3];
    return status;
}
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

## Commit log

2026-03-10 Create project files
    [TC358870_DEMO.DSN]
2026-03-10 Add Type-C power input
    [TC358870_DEMO.DSN]
2026-03-10 Add DC-DC 5V to 3.3V converter circuit
    [TC358870_DEMO.DSN]
2026-03-10 Add DC-DC 3.3V to LDO 1.8V converter circuit
    [TC358870_DEMO.DSN]
2026-03-10 Add DC-DC 5V to 1.1V converter circuit
    [TC358870_DEMO.DSN]
2026-03-10 Add DC-DC 3.3V to LDO 1.2V converter circuit
    [TC358870_DEMO.DSN]
2026-03-10 Add IN 5V to LED(12V MAX) converter circuit
    [TC358870_DEMO.DSN]
2026-03-13 Modify the schematic page naming and delete the LED driver circuit.
    [TC358870_DEMO.DSN]
2026-03-14 Add IN 3.3V DCDC to LED DCDC (22mA MAX) converter circuit
    [TC358870_DEMO.DSN]
2026-03-16 Add 5V IN to LCD ±5.5V converter circuit
    [TC358870_DEMO.DSN]
2026-03-16 Add HDMI connector and ESD protection for HDMI signal
    [TC358870_DEMO.DSN]
2026-03-16 Add TC358870 and configure its power and HDMI I/O.
    [TC358870_DEMO.DSN]
2026-03-16 Complete the connection of TC358870
    [TC358870_DEMO.DSN]
2026-03-16 Complete the LS029B3SX01 interface connection.
    [TC358870_DEMO.DSN]
2026-03-17 Add an external HDR-TH interface
    [TC358870_DEMO.DSN]
2026-03-17 Create layout file
    [TC358870_DEMO.DSN, cases.cfg, tc358870_demo.brd]
2026-03-17 Set up stacking
    [TC358870_DEMO.DSN, cases.cfg, tc358870_demo.brd]
2026-03-18 Complete the layout of HDMI and Type-C interfaces.
    [bf.brd, tc358870_demo.brd]
2026-03-18 Complete the layout of DC-DC 3.3V and DC-DC 1.1V.
    [bf.brd, tc358870_demo.brd]
2026-03-18 Complete the layout of LDO 1.8V and LDO 1.2V.
    [bf.brd, tc358870_demo.brd]
2026-03-18 Complete the layout of 5V IN to LCD ±5.5V and 3V3 DC to LED DC (22mA).
    [bf.brd, tc358870_demo.brd]
2026-03-18 Simple partitioning
    [bf.brd, tc358870_demo.brd]
2026-03-19 Complete layout
    [TC358870_DEMO.DSN, bf.brd, tc358870_demo.brd]
2026-03-19 Rules set up
    [TC358870_DEMO.DSN, bf.brd, tc358870_demo.brd]
2026-03-19 Board drawing
    [bf.brd, tc358870_demo.brd]
2026-03-19 LDO power cabling completed.
    [bf.brd, tc358870_demo.brd]
2026-03-19 DCDC power cabling completed.
    [bf.brd, tc358870_demo.brd]
2026-03-23 DCDC LED power cabling completed.
    [TC358870_DEMO.DSN, bf.brd, tc358870_demo.brd]
2026-03-23 Complete HDMI cabling
    [bf.brd, tc358870_demo.brd]
2026-03-23 Complete the routing of MIPI_0.
    [bf.brd, tc358870_demo.brd]
2026-03-23 Complete the routing of MIPI_1.
    [bf.brd, tc358870_demo.brd]
2026-03-24 Complete wiring
    [TC358870_DEMO.DSN, bf.brd, cases.cfg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]
2026-04-21 Export PCB fabrication file
    [#Taaaahm19560.brd, IDARpResult.csv, bf.brd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]
2026-04-21 Export HAL project
    [TC358870_DEMO.DSN]
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2026-04-22 Refactor I2C read/write with retry logic and timeout handling
2026-04-22 Implement basic I2C read/write functions and chip identification for the TC358870 bridge.
2026-04-25 Add professional README with PCB design documentation
    Detailed README covering the TC358870XBG evaluation board: block diagram,
    4-layer stack-up, high-speed routing constraints (HDMI/MIPI DSI @ 100 Ohm
    differential), power tree with ripple requirements, I2C register map,
    fabrication outputs (Gerber), and signal integrity simulation data.
2026-05-05 @ Deprecate Rev 1.0 PCB — document screen-burn errata, add design notes, and move Allegro files to deprecated/
    - README: add project code (tb), PCB deprecation notice, Rev 2.0 plan links, and screen-burn errata row
    - design-notes.md: new working document with project info, PCB naming standard, Rev history, screen-burn root cause, and lessons learned (PCB + firmware)
    - .vscode/settings.json: mark design-notes.md as project working document
    - .gitignore: add *.brd, *.jrl*, *.DSNlck, gerber*, *.zip patterns; ignore entire deprecated/ folder
    - Move all allegro/ design files to deprecated/ (Rev 1.0 — abandoned due to DSI lane ordering error)
    @
    [#Taaaahm19560.brd, IDARpResult.csv, bf.brd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]
2026-06-26 feat: complete 5V-to-1V1 DCDC, 5V-to-3V3 DCDC, and Type-C power input layout and routing; fix .gitignore for OrCAD single-digit auto-save files
    [TC358870_DEMO.DSN, TC358870_DEMO.bom.xlsx, cases.cfg]
2026-06-27 refactor: complete 3V3 DCDC-to-1V8 LDO and 3V3 DCDC-to-1V2 LDO layout and routing; restore tc358870_demo.brd to version control
    [TC358870_DEMO.DSN, tc358870_demo.brd]
2026-06-27 feat: complete 3V3 DC to LED DC (22mA) layout and routing
    [tc358870_demo.brd]
2026-06-27 feat: complete 5V IN to LCD ±5.5V charge pump layout and routing
    [TC358870_DEMO.DSN, tc358870_demo.brd]
2026-06-27 feat: complete HDMI IN and HDMI DDR EEPROM layout and routing
    [tc358870_demo.brd]
2026-06-27 feat: complete TC358870 filter/clock/reset layout and routing
    [tc358870_demo.brd]
2026-06-27 feat: complete full PCB layout and routing
    [tc358870_demo.brd]
2026-06-28 feat: complete PDN power plane routing and HDMI routing with length matching
    [cases.cfg, tc358870_demo.brd]
2026-06-28 feat: complete TC358870 fanout and power routing
    [tc358870_demo.brd]
2026-06-28 feat: complete MIPI DSI1 routing and length matching (SI/PI simulation pending)
    [tc358870_demo.brd]
2026-06-29 feat: add GND copper pour on L3 for MIPI DSI1 layer-transition reference plane (L1->L4)
    [tc358870_demo.brd]
2026-06-29 feat: complete MIPI DSI0 routing and all remaining routing — layout done, SI/PI simulation pending
    [tc358870_demo.brd]
2026-06-29 feat: add dedicated GND reference trace on L4 for I2C, spanning L2/L3 split-plane crossing
    [tc358870_demo.brd]
2026-06-29 chore: remove OrCAD auto-save artifacts, stale root copies, and generated reports; update .gitignore
    [cases.cfg]
2026-06-29 docs: fix README component designators and power tree to match schematic; add EDIF schematic export; update AT24C02 value
    [TC358870_DEMO.DSN]
2026-06-29 fix: rework HDMI schematic for reflection matching — delete layout, add series termination resistors
    [TC358870_DEMO.DSN, tc358870_demo.brd]
2026-06-29 docs: add SI simulation workflow screenshots (coupling, crosstalk, impedance, reflection)
2026-06-29 fix: re-route HDMI with matched impedance — SI/PI simulation passed
    [tc358870_demo.brd]
2026-06-29 feat: add Rev 2.0 Gerber fabrication files; allow gerber.zip in gitignore
    [tc358870_demo.brd]
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2026-07-08 chore: update PCB schematic, project file, and add simulation data
    [#Taaaach15224.brd, #Taaaafg15224.brd, #Taaaafo15224.brd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]
2026-07-08 feat: add LS029B3SX01 EDID template and fix declaration to EDID.c
    [EDID.c]
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2026-07-08 refactor: add const correctness to EDID and AT24C02 write paths
    [AT24C02.c, EDID.c]
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
